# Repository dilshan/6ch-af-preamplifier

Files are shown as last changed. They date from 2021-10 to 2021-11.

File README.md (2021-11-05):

# 5.1 channel audio preamplifier

This project introduces a digitally controlled 5.1 channel audio preamplifier system. This amplifier is specifically designed to increase the gain of the multi-channel PC sound cards.

This preamplifier consists of six *[TL074](https://octopart.com/tl074idt-stmicroelectronics-410591)*/*[TL072](https://octopart.com/tl072idt-stmicroelectronics-410448)* preamplifier stages and *[PT2258](http://www.princeton.com.tw/Portals/0/Product/PT2258.pdf)* electronic volume control. The input stage of this preamplifier consists of six *TL074*/*TL072* buffer stages. The *[PIC16F886](https://www.microchip.com/en-us/product/PIC16F886)* microcontroller manages the *PT2258* electronic volume control IC. All the volume levels and menu options are displayed on [*HD44780*, 16×2 character LCD screen](https://s.click.aliexpress.com/e/_9iRz4T).

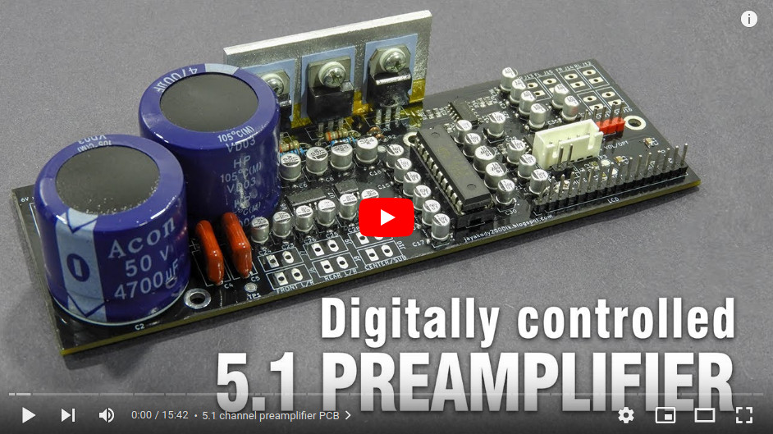
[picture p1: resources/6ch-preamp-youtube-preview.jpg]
5.1 Preamplifier Video (https://youtu.be/Fg2yn0mBOQU)


The provided PCB design contains a preamplifier, buffer stages, digital volume control circuit, driver circuit, and power supply unit.

The project was sponsored by *[PCBWay](https://www.pcbway.com/setinvite.aspx?inviteid=341430)*. The accurately configured PCB of this preamplifier can directly [order from *PCBWay*](https://www.pcbway.com/project/shareproject/5_1_channel_audio_preamplifier.html) through their website. The dimension of the PCB is 151.45 × 50.76mm.

This preamplifier is a [certified](https://certification.oshwa.org/lk000010.html) open hardware project. All source codes, *KiCAD* design files, and compiled binaries are available at this repository.

The complete [documentation](https://github.com/dilshan/6ch-af-preamplifier/wiki) of this project is available in the [wiki](https://github.com/dilshan/6ch-af-preamplifier/wiki) section of this repository. The PCB *Gerber files* and compiled binaries are also available in the [release](https://github.com/dilshan/6ch-af-preamplifier/releases) section of this repository.

All the content of this project are distributed under the terms of the following license:

- Hardware License: [CERN-OHL-W 2.0](https://ohwr.org/cern_ohl_w_v2.txt)
- Software License: [MIT](https://github.com/dilshan/6ch-af-preamplifier/blob/main/LICENSE)
- [Documentation](https://github.com/dilshan/6ch-af-preamplifier/wiki) License: [CC BY 4.0](https://creativecommons.org/licenses/by/4.0/)

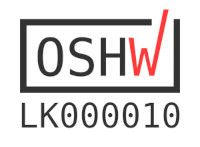
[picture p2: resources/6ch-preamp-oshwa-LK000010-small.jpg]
LK000010 (https://certification.oshwa.org/lk000010.html)


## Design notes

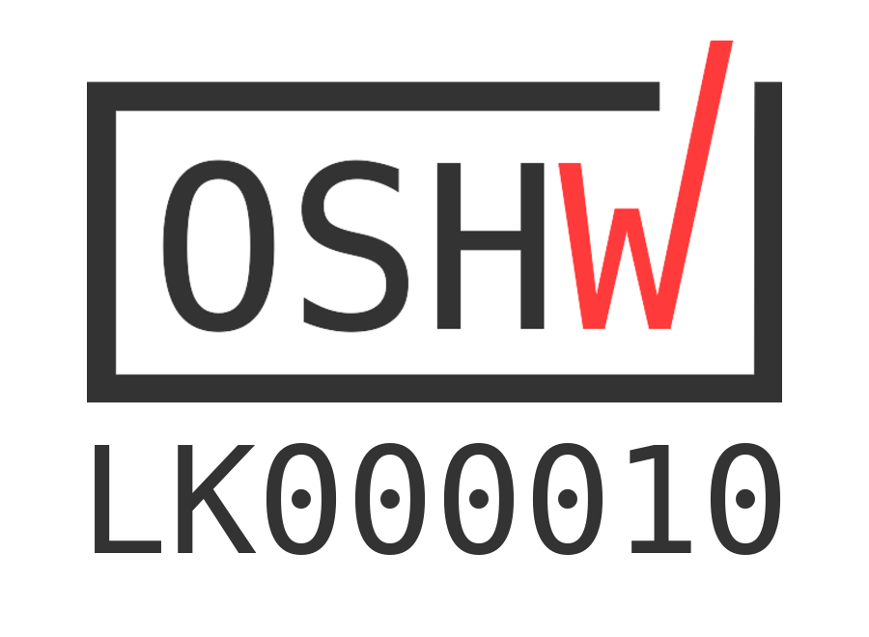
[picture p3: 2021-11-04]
resources/6ch-preamp-oshwa-LK000010.png

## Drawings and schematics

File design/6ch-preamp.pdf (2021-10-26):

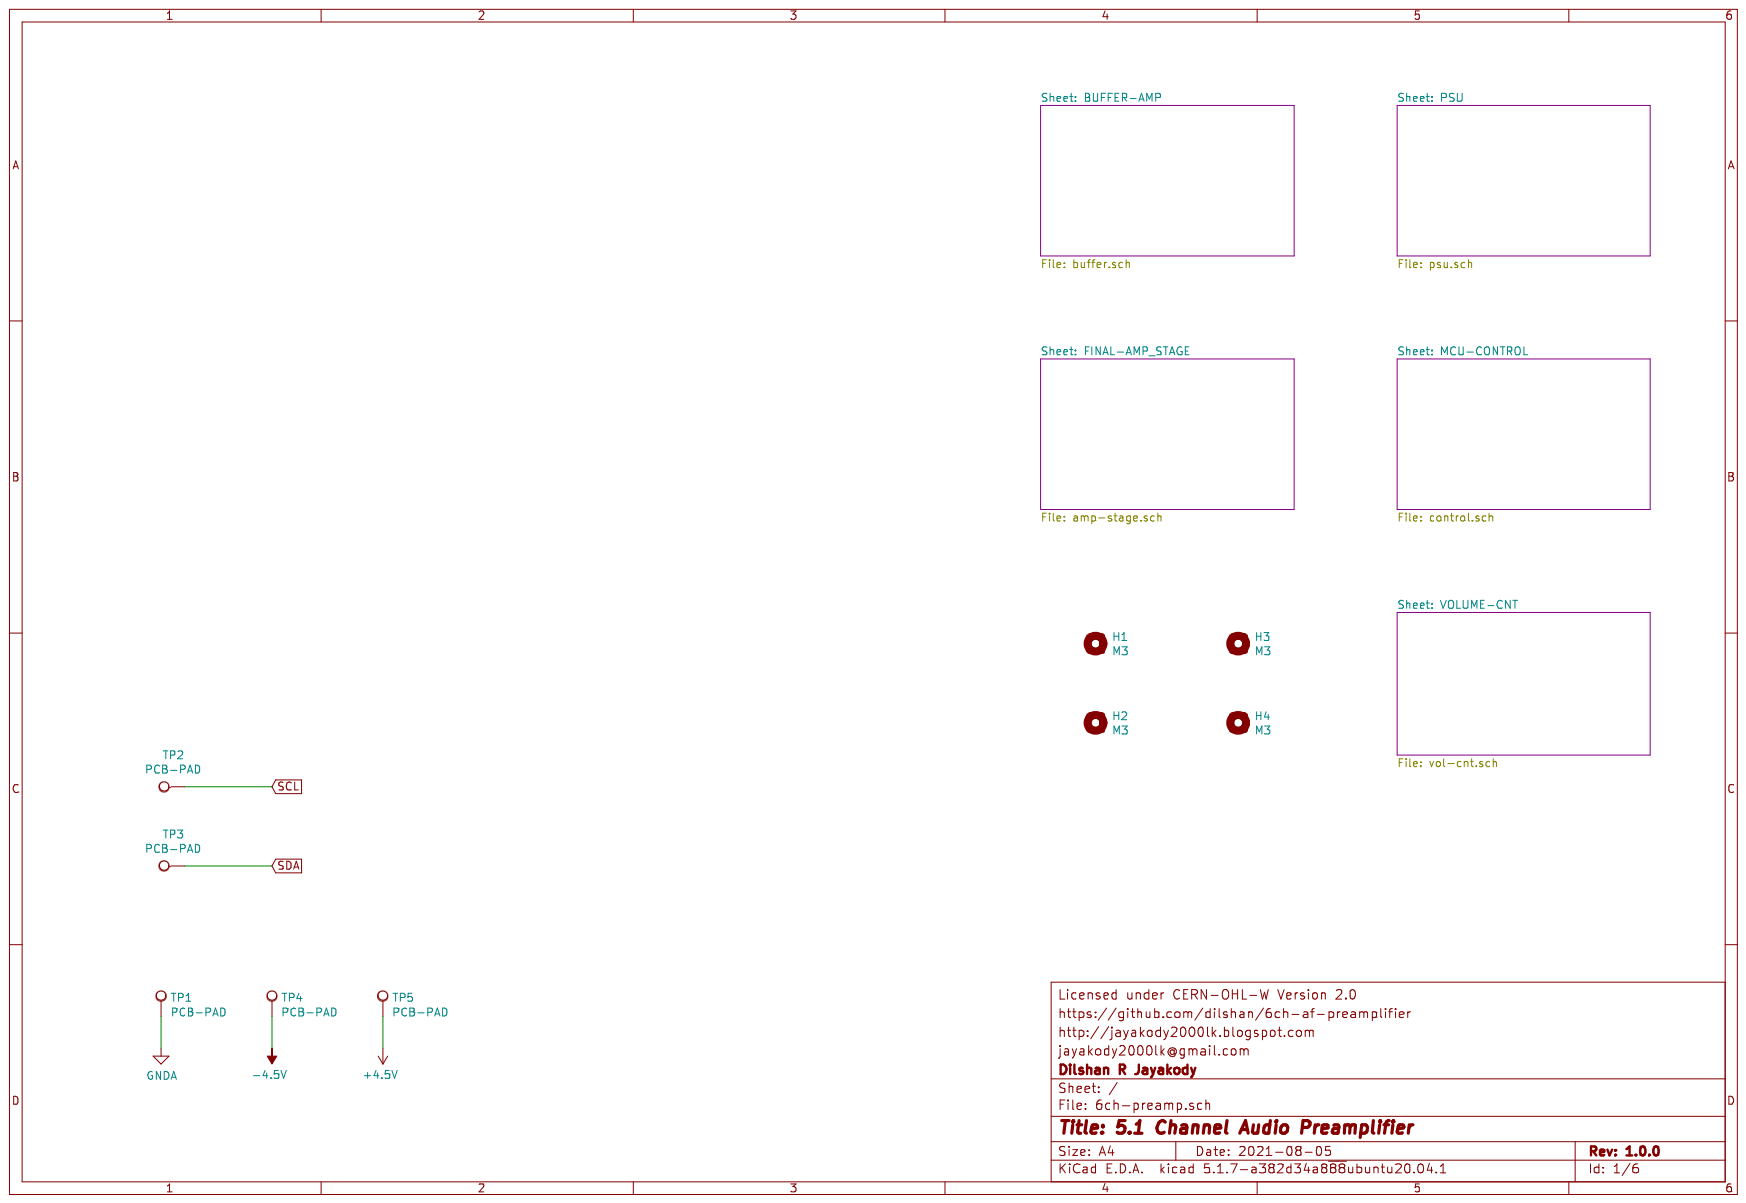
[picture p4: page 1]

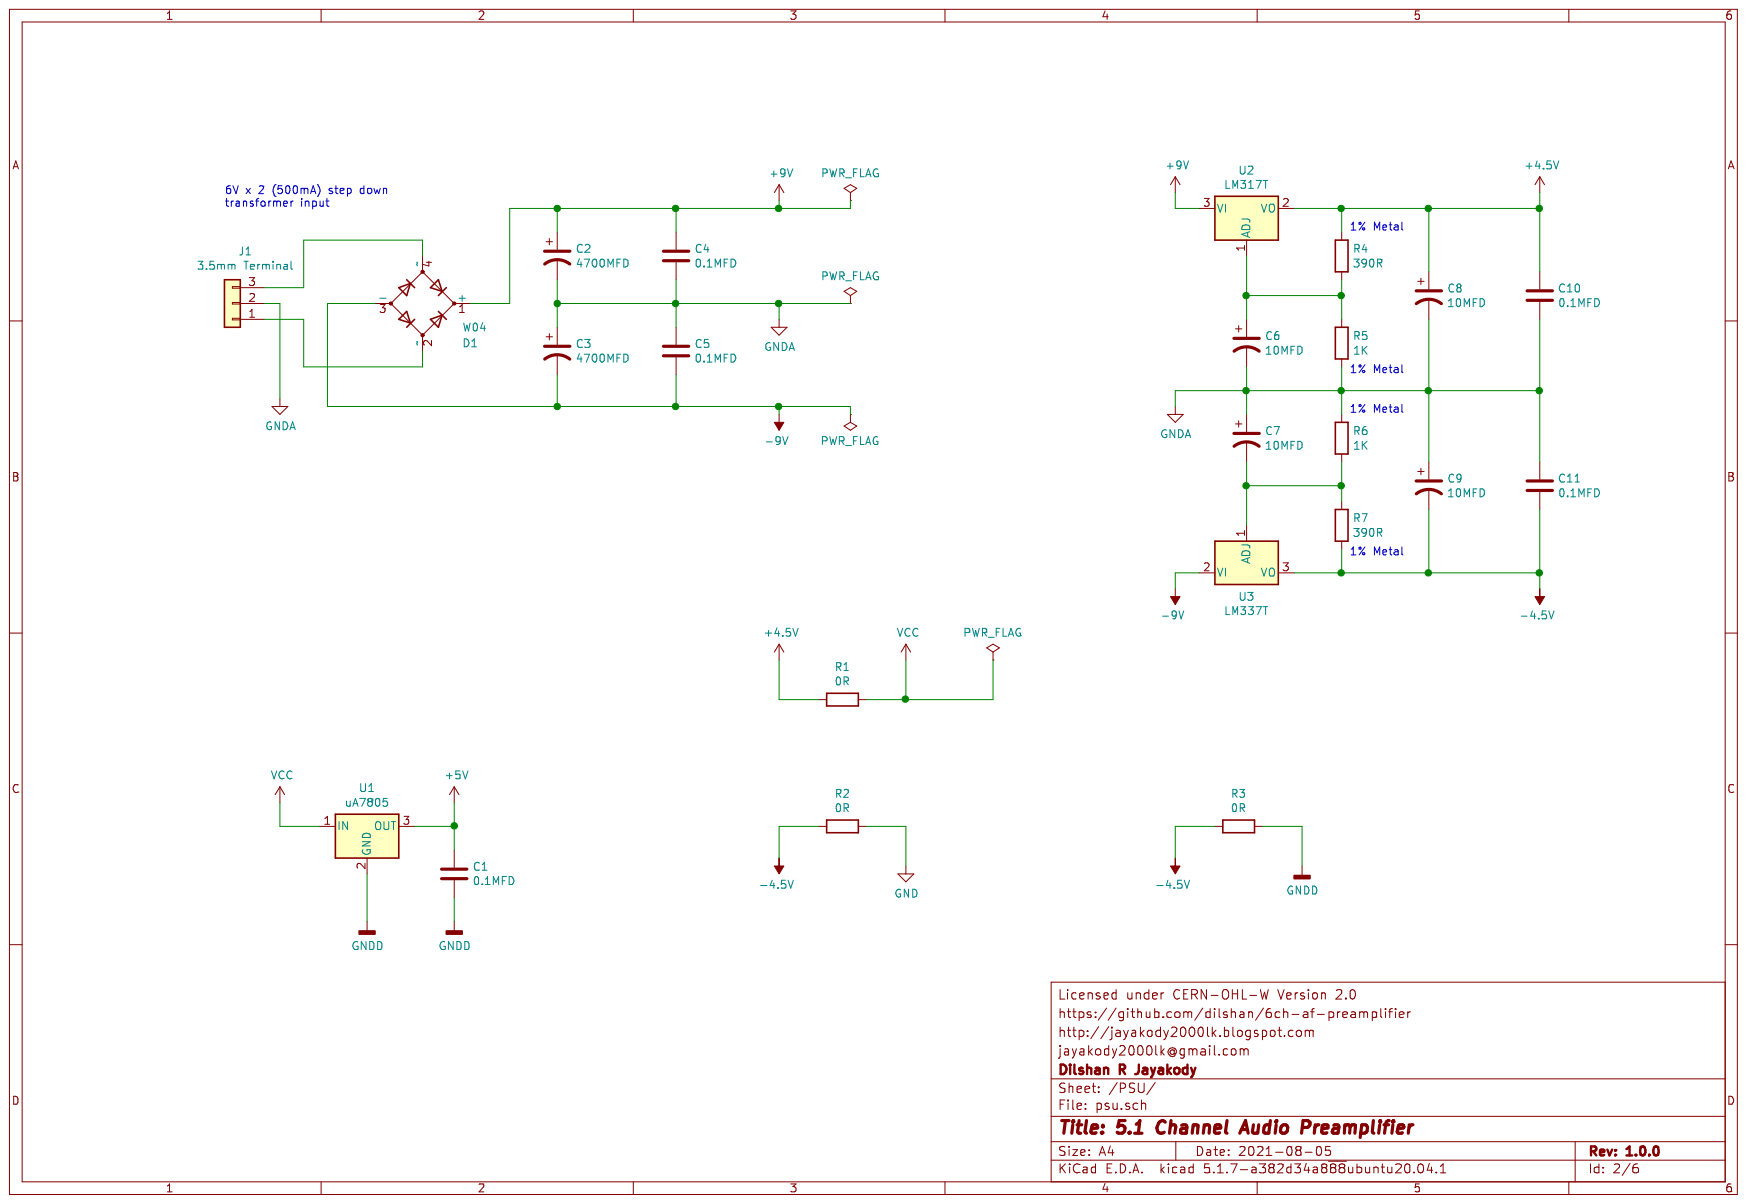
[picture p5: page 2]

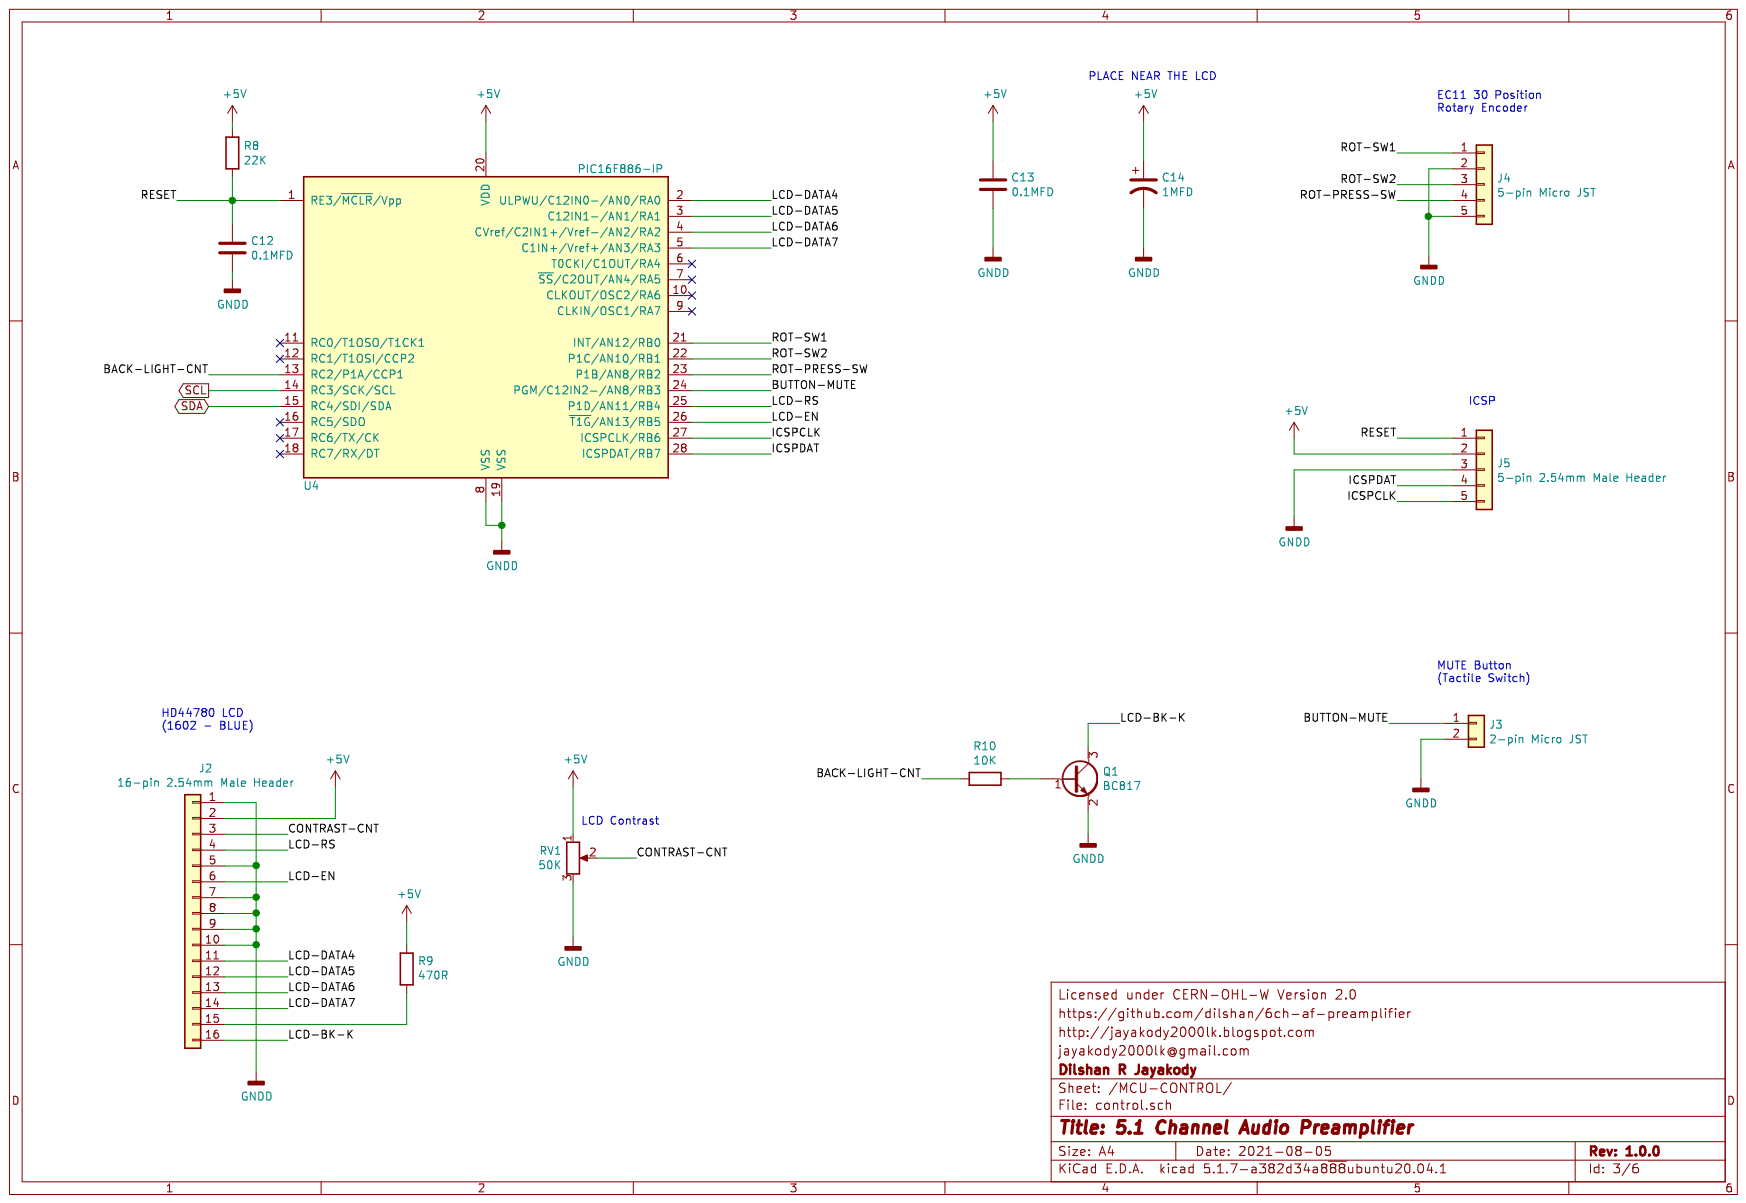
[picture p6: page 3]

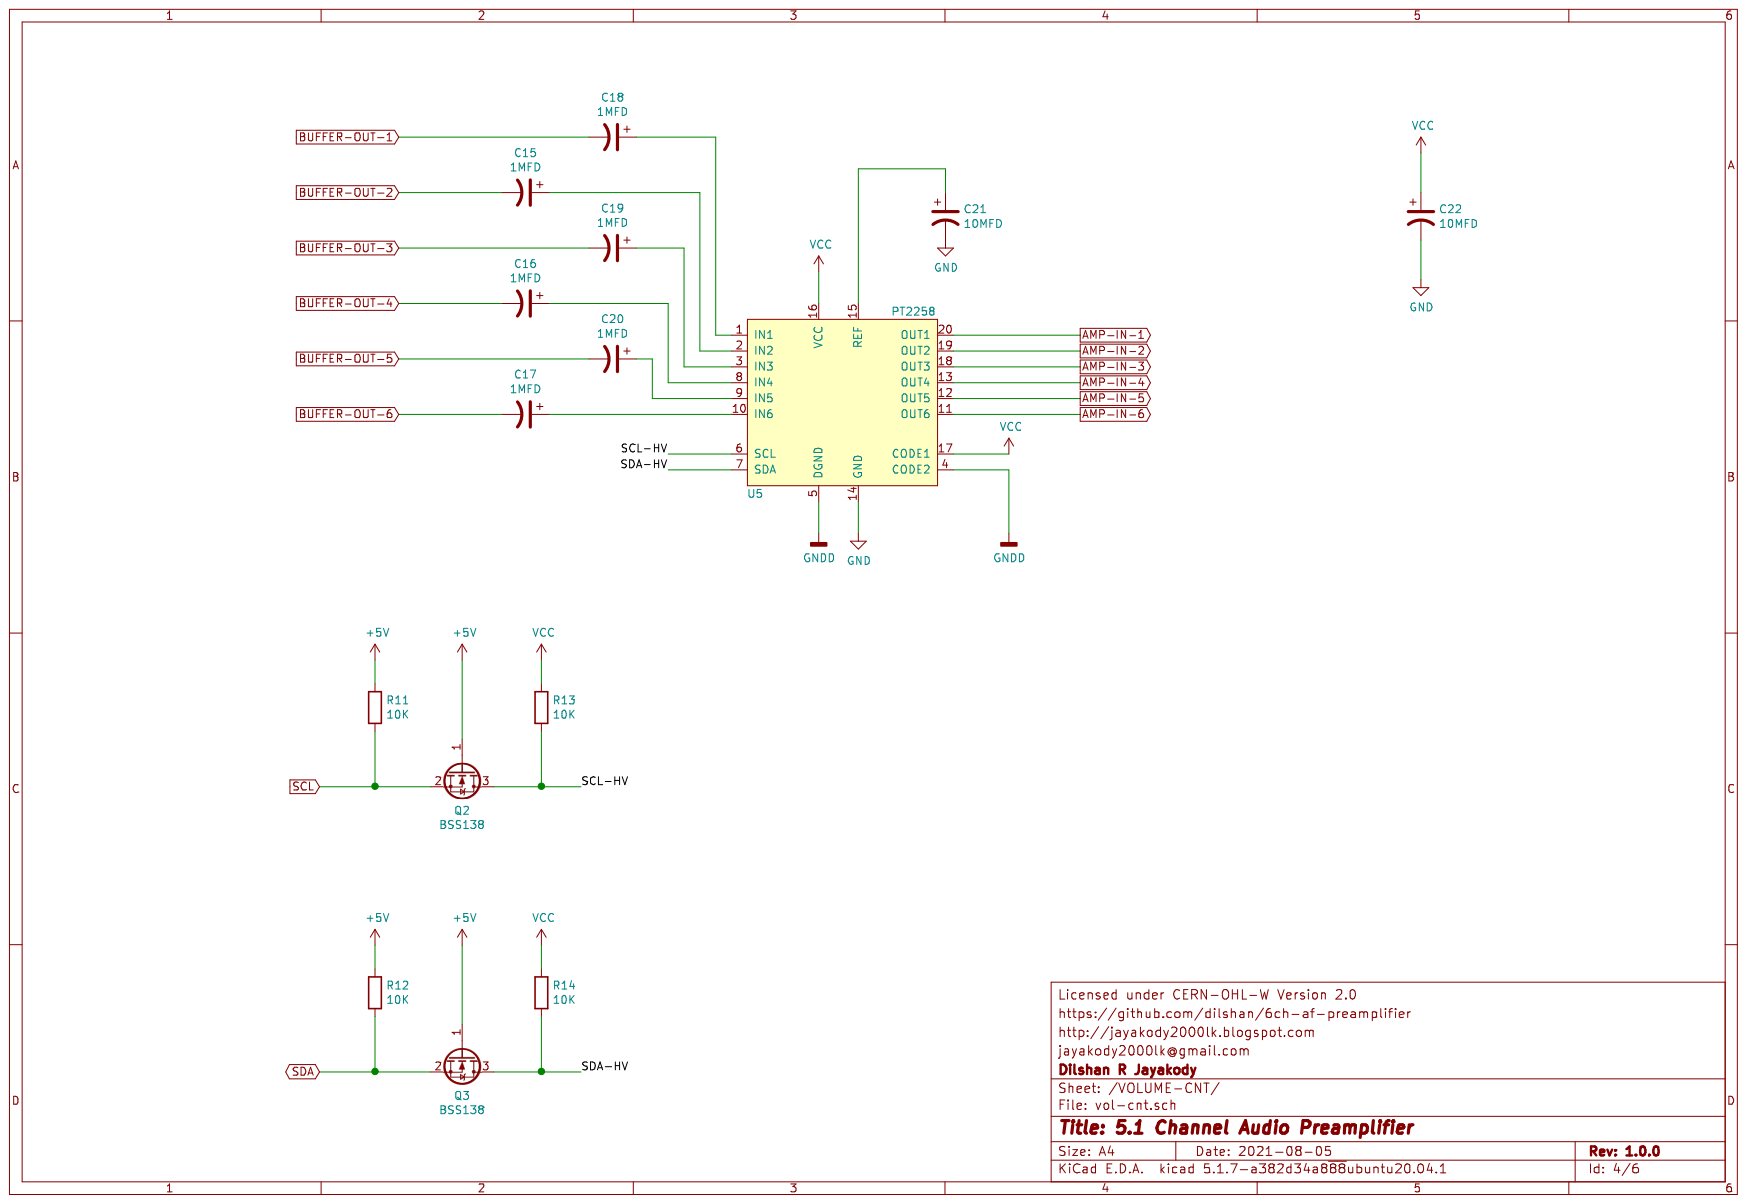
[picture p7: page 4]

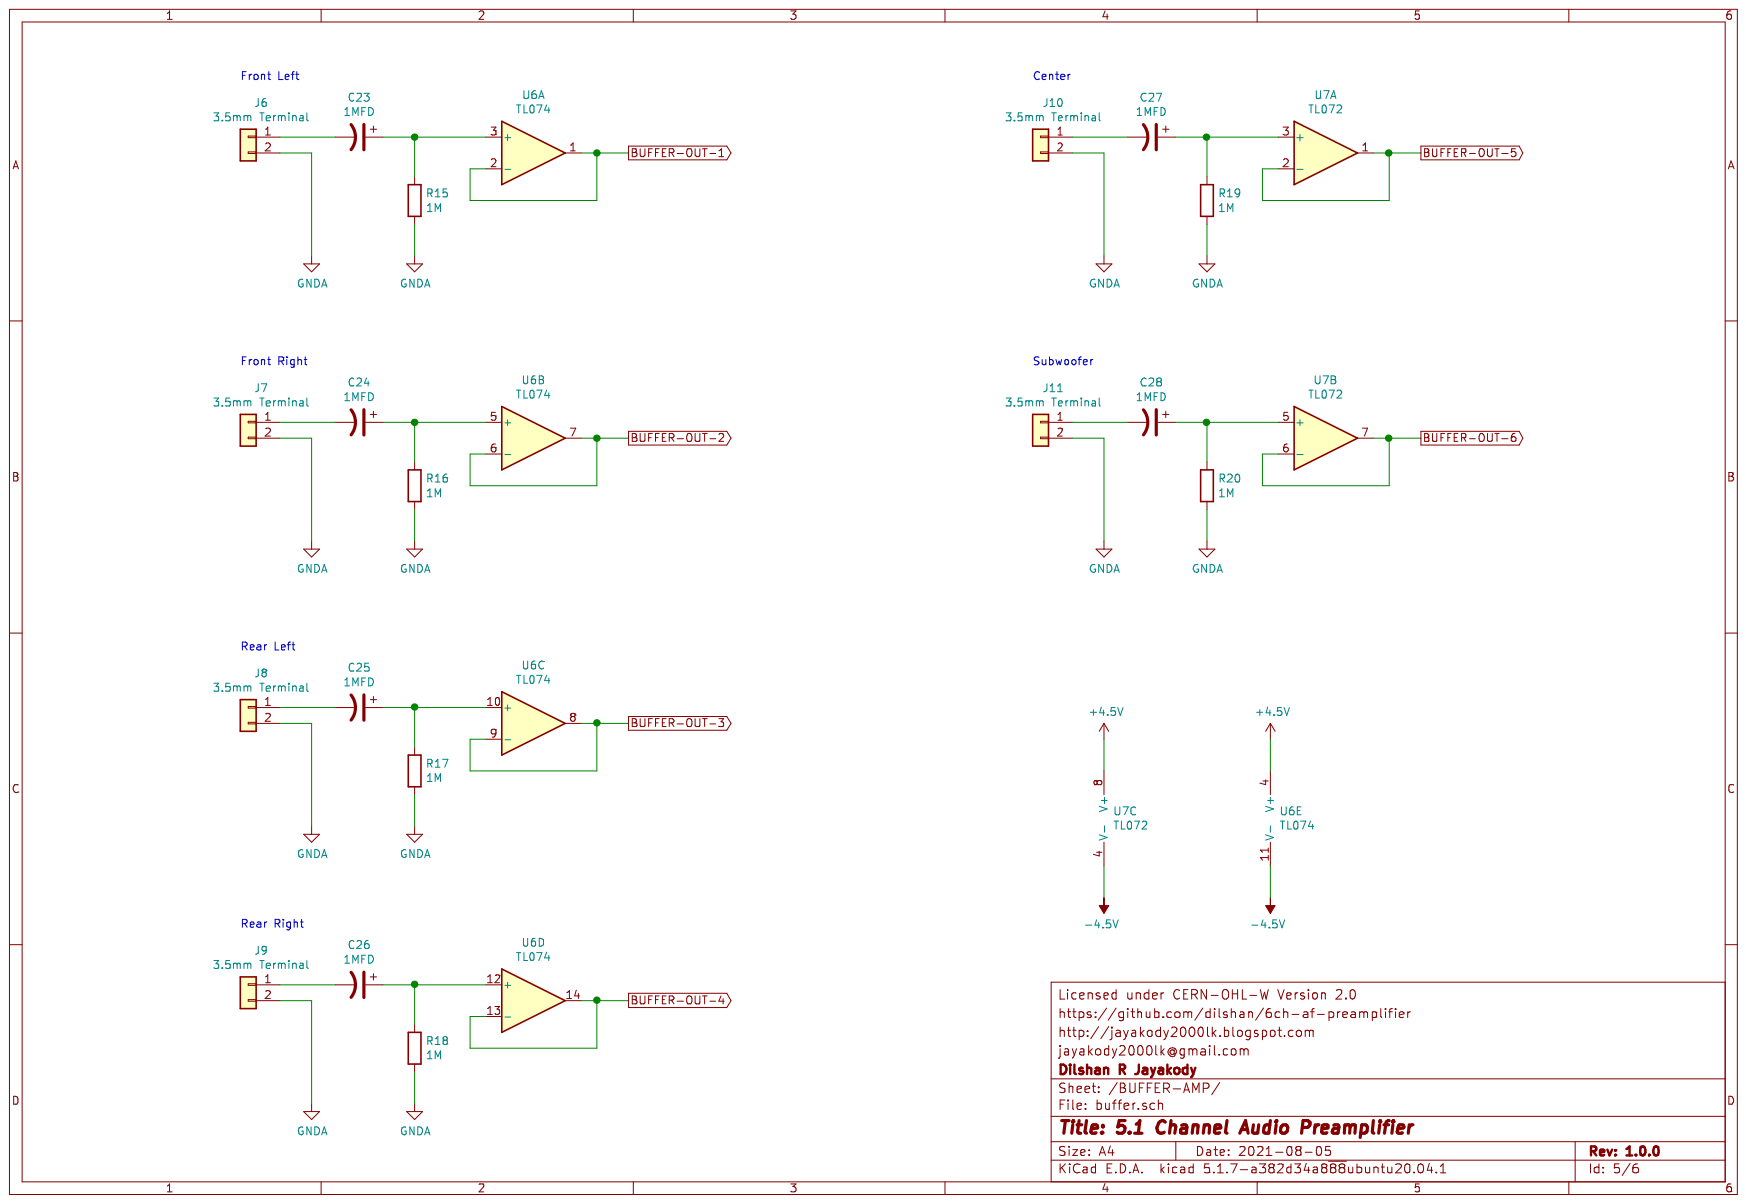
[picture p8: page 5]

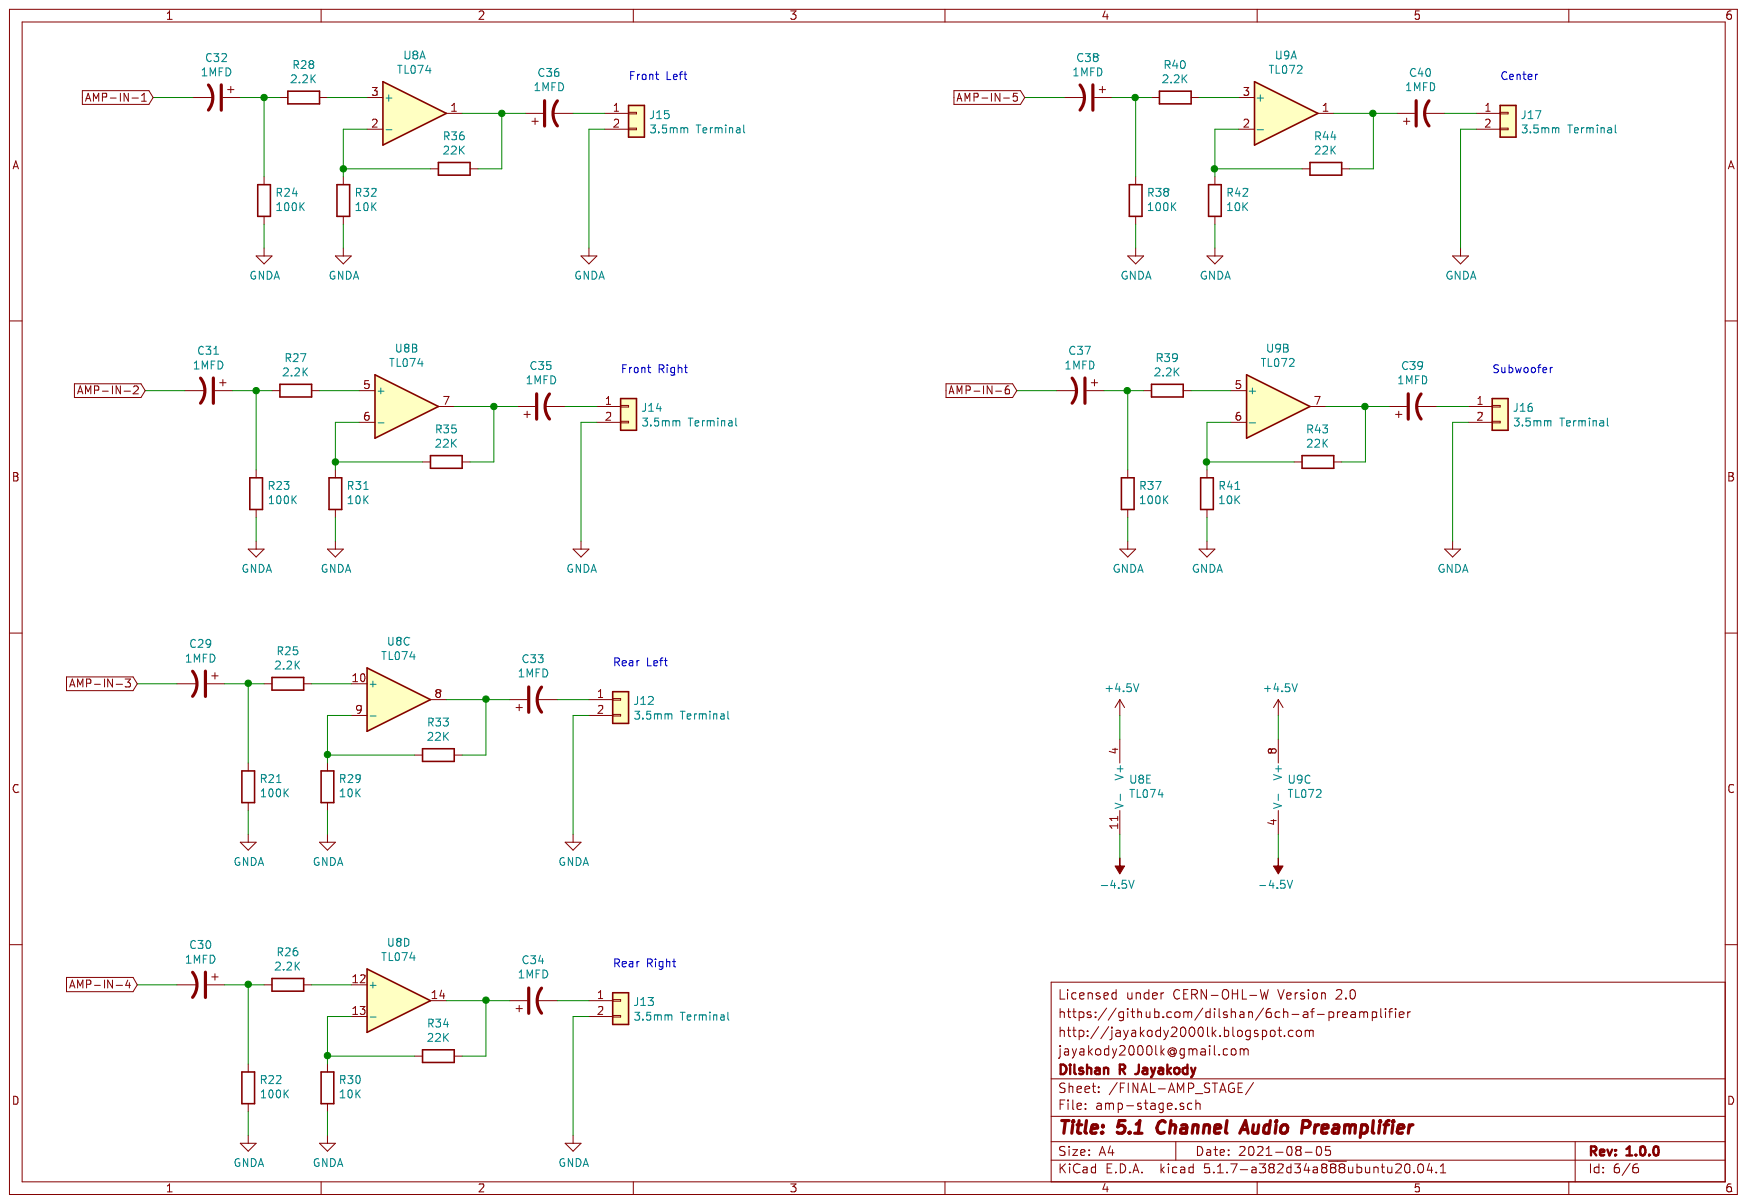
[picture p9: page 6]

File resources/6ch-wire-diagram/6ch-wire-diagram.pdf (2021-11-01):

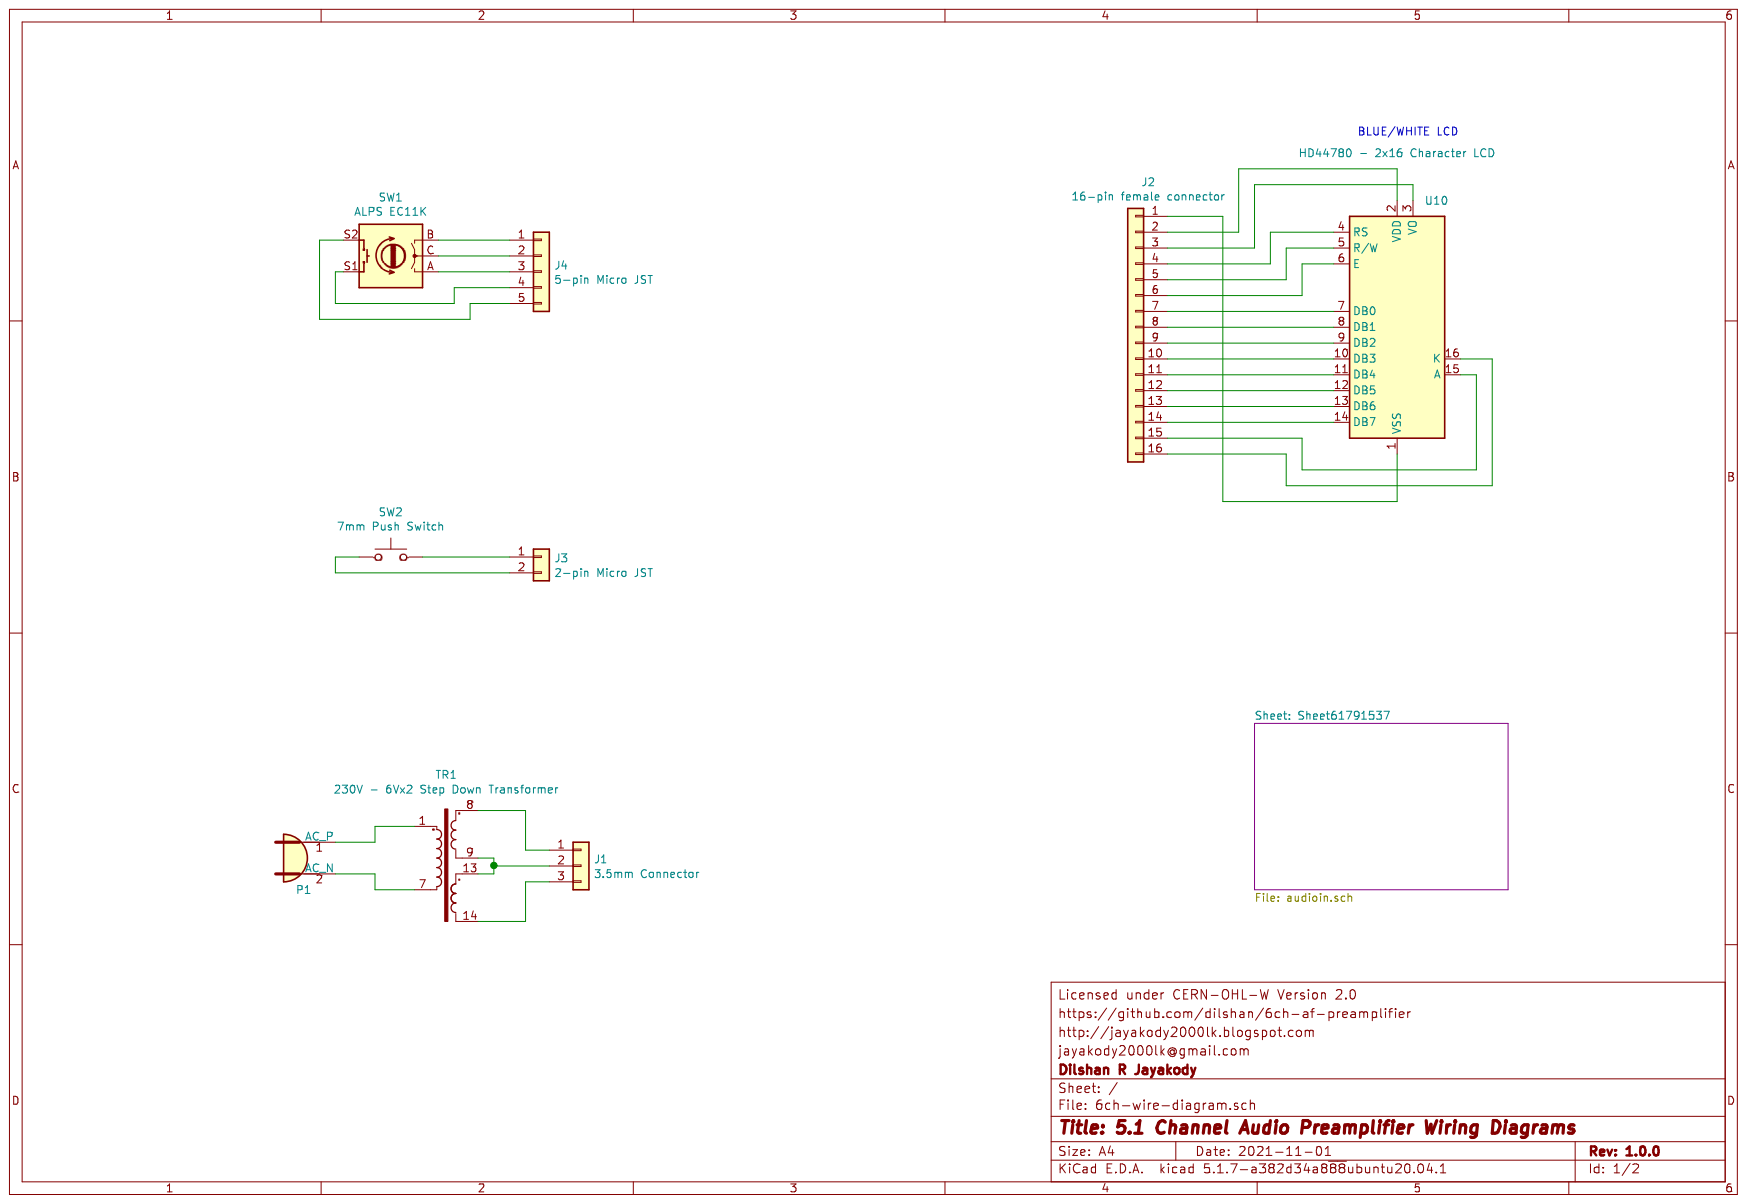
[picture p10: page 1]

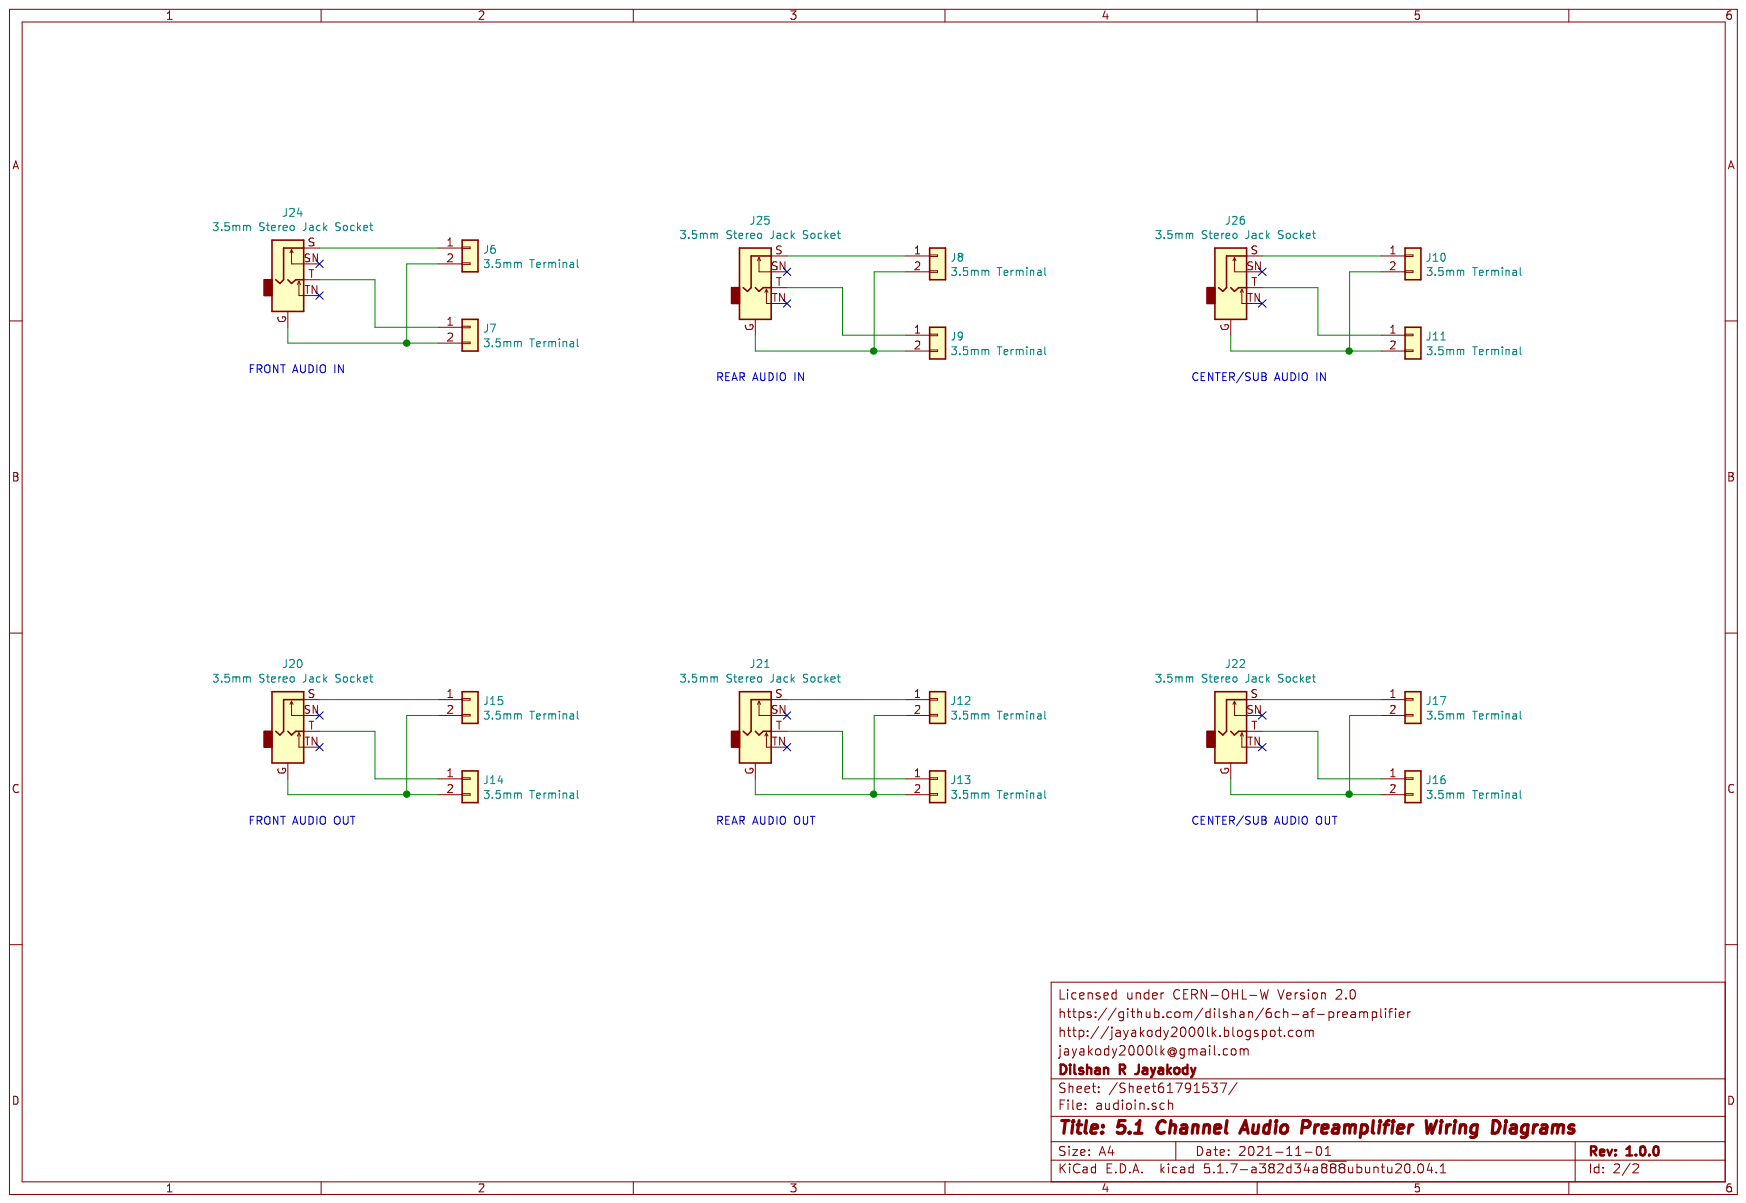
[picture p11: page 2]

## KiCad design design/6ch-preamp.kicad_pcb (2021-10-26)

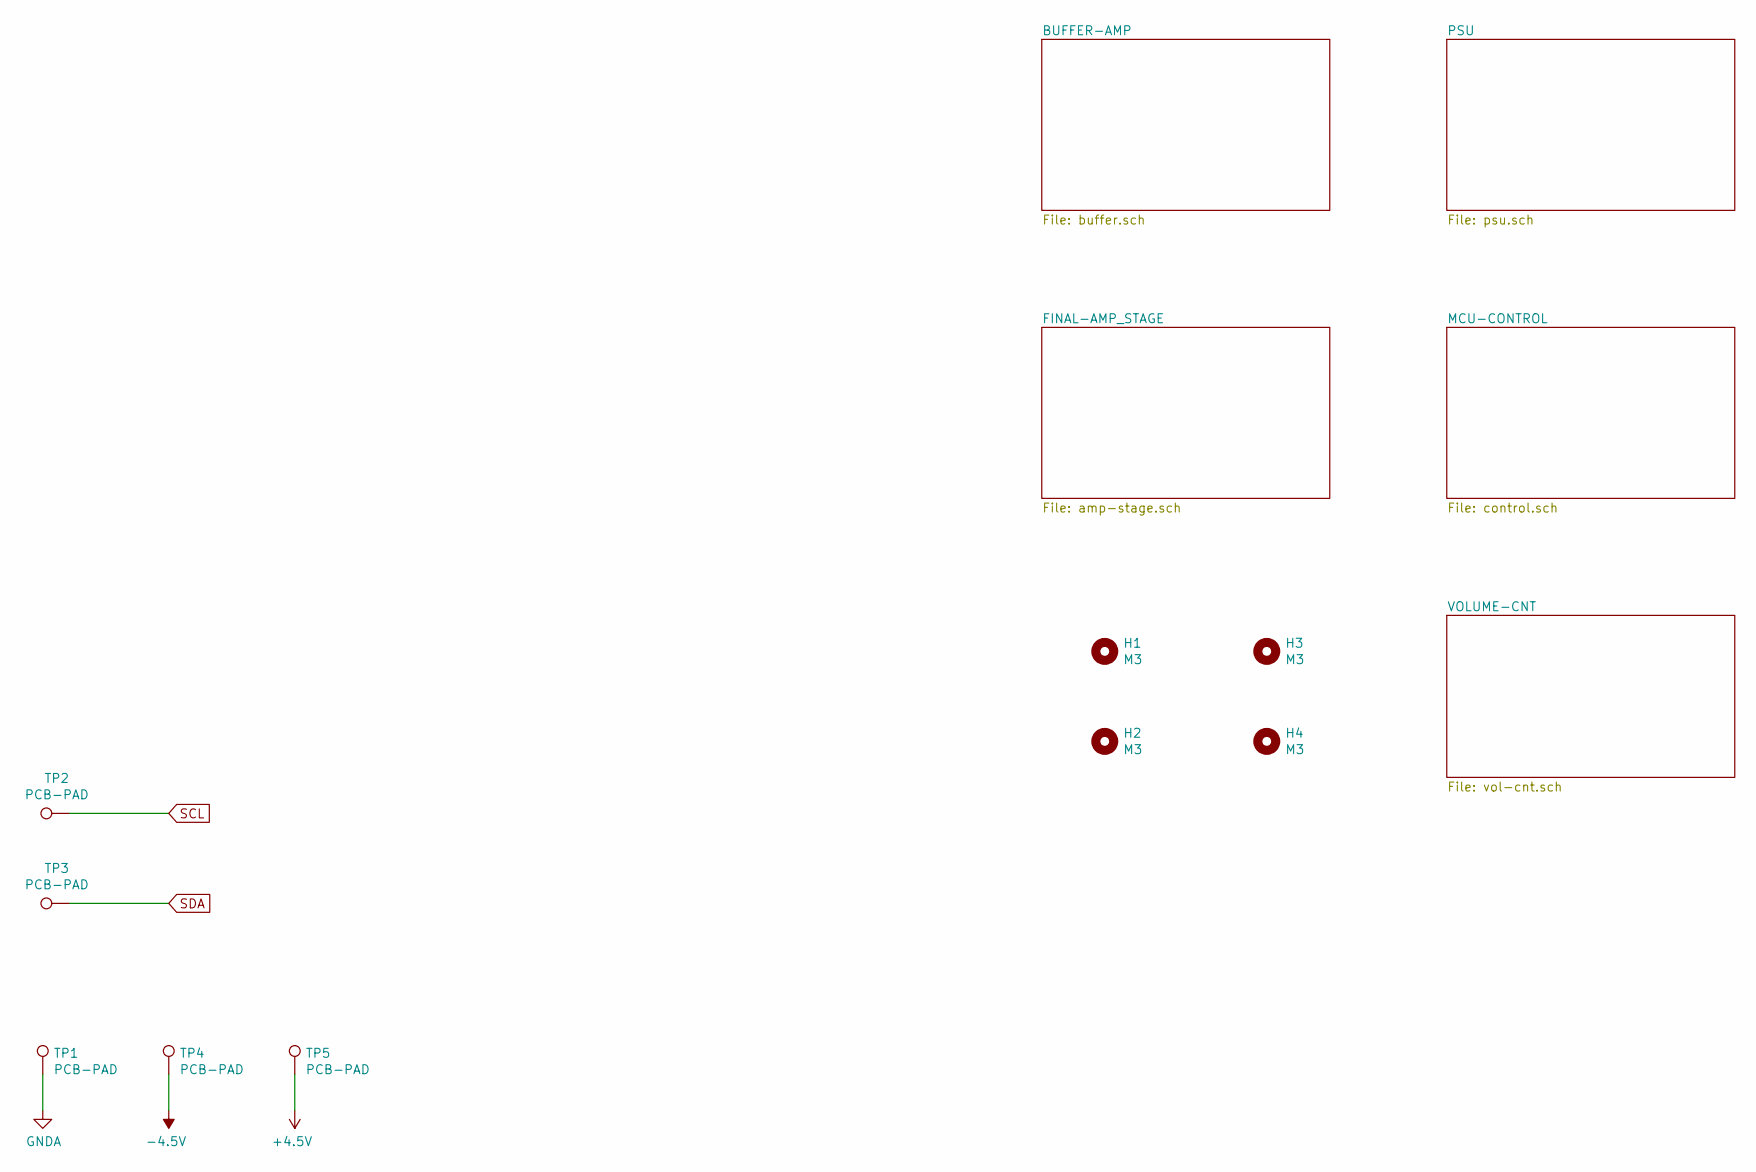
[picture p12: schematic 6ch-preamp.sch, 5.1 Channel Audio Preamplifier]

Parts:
H1, H2, H3, H4: M3; MountingHole_3.2mm_M3_DIN965_Pad
TP1, TP2, TP3, TP4, TP5: PCB-PAD; TestPoint_Pad_D2.0mm

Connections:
+1V35: TP5.1; also elsewhere on the board
-5V: TP4.1; also elsewhere on the board
GNDA: TP1.1; also elsewhere on the board
SCL: TP2.1; also elsewhere on the board
SDA: TP3.1; also elsewhere on the board

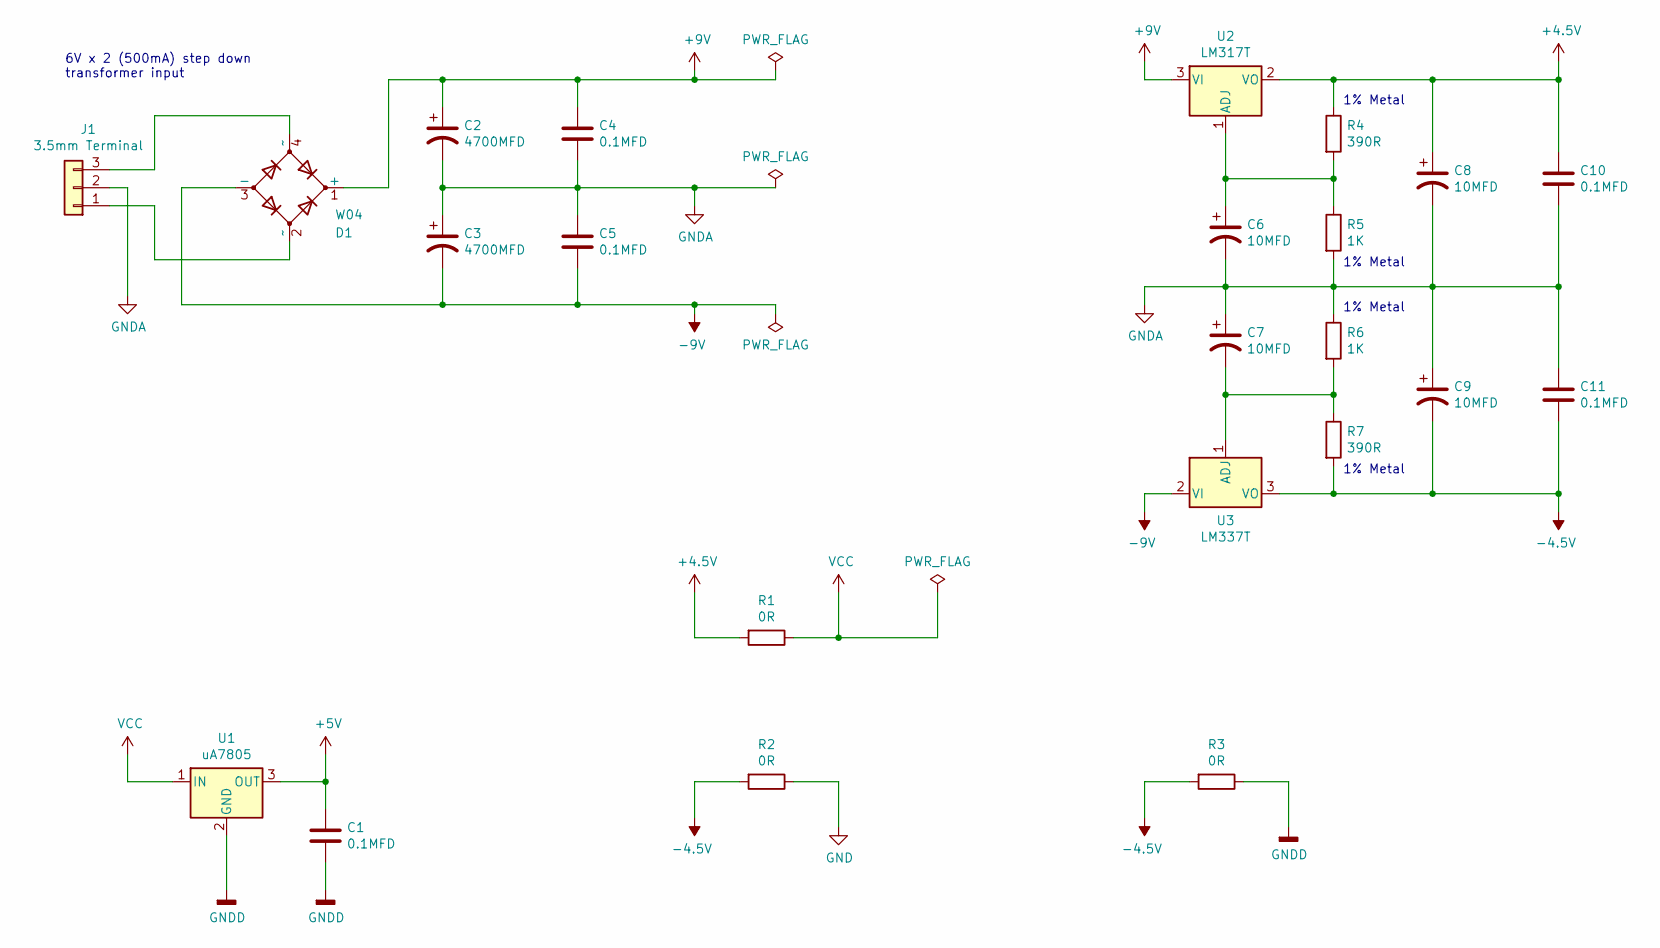
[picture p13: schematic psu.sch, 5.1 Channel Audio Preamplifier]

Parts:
C1, C10, C11: 0.1MFD; C_0805_2012Metric_Pad1.18x1.45mm_HandSolder
C2, C3: 4700MFD; CP_Radial_D30.0mm_P10.00mm_SnapIn
C4, C5: 0.1MFD; C_Disc_D10.5mm_W5.0mm_P10.00mm
C6, C7, C8, C9: 10MFD; CP_Elec_5x5.3
D1: W04; Diode_Bridge_Round_D9.0mm
J1: 3.5mm Terminal; PhoenixContact_MCV_1,5_3-G-3.5_1x03_P3.50mm_Vertical
R1, R2, R3: 0R; R_Axial_DIN0204_L3.6mm_D1.6mm_P2.54mm_Vertical
R4, R7: 390R; R_Axial_DIN0207_L6.3mm_D2.5mm_P10.16mm_Horizontal
R5, R6: 1K; R_Axial_DIN0207_L6.3mm_D2.5mm_P10.16mm_Horizontal
U1: uA7805; TO-220-3_Vertical
U2: LM317T; TO-220-3_Vertical
U3: LM337T; TO-220-3_Vertical

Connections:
+1V35: C8.1, C10.1, R1.2, R4.1, U2.2 (VO); also elsewhere on the board
+5V: C1.1, U1.3 (OUT); also elsewhere on the board
+9V: C2.1, C4.1, D1.1 (+), U2.3 (VI)
-5V: C9.2, C11.2, R2.2, R3.2, R7.2, U3.3 (VO); also elsewhere on the board
-9V: C3.2, C5.2, D1.3 (-), U3.2 (VI)
GND: R2.1; also elsewhere on the board
GNDA: C2.2, C3.1, C4.2, C5.1, C6.2, C7.1, C8.2, C9.1, C10.2, C11.1, J1.2, R5.2, R6.1; also elsewhere on the board
GNDD: C1.2, R3.1, U1.2 (GND); also elsewhere on the board
unnamed: C6.1, R4.2, R5.1, U2.1 (ADJ)
unnamed: C7.2, R6.2, R7.1, U3.1 (ADJ)
unnamed: D1.2 (~~), J1.1
unnamed: D1.4 (~~), J1.3
VCC: R1.1, U1.1 (IN); also elsewhere on the board

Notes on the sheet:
6V x 2 (500mA) step down transformer input
1% Metal

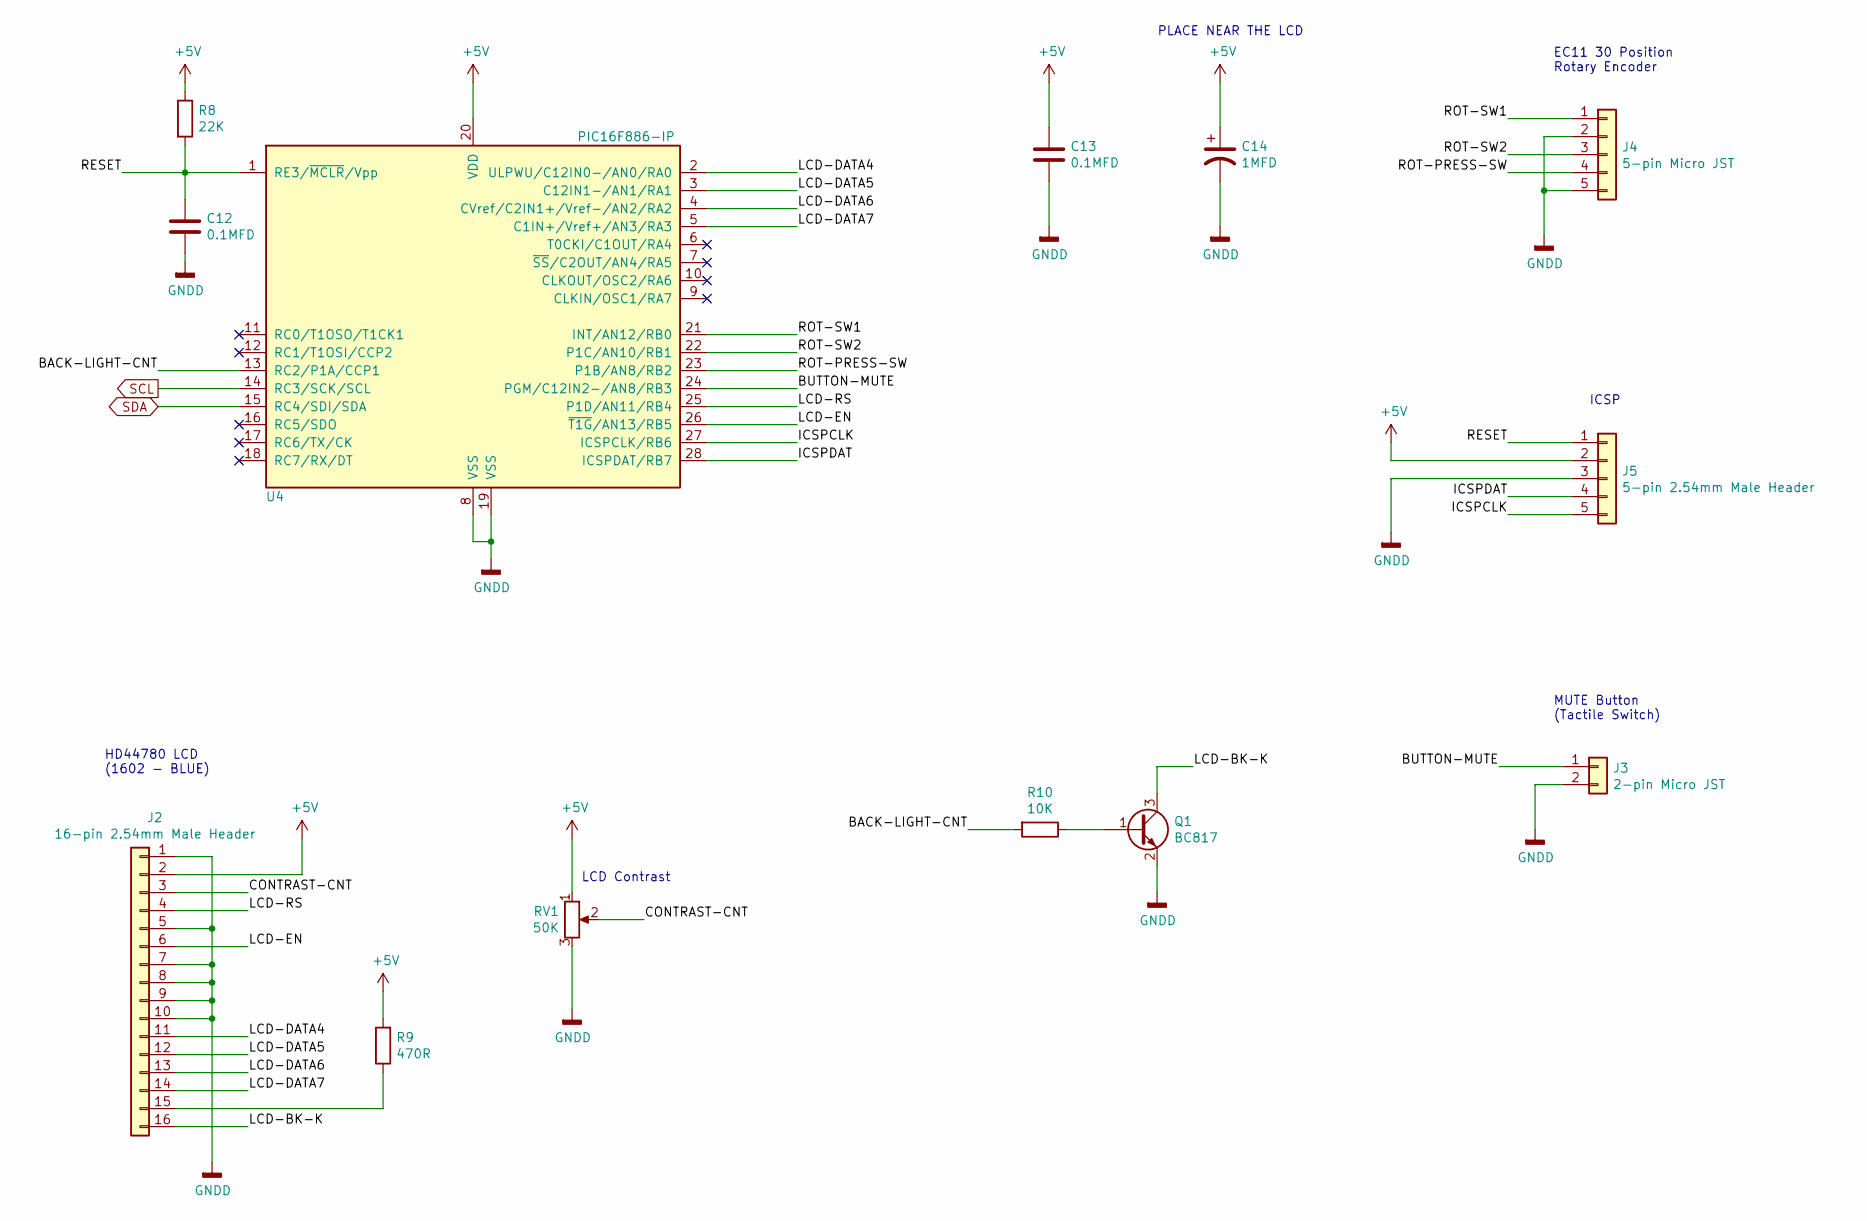
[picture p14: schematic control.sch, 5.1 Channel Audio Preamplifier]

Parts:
C12, C13: 0.1MFD; C_0805_2012Metric_Pad1.18x1.45mm_HandSolder
C14: 1MFD; CP_Elec_4x5.3
J2: 16-pin 2.54mm Male Header; PinHeader_1x16_P2.54mm_Vertical
J3: 2-pin Micro JST; JST_EH_B2B-EH-A_1x02_P2.50mm_Vertical
J4: 5-pin Micro JST; JST_EH_B5B-EH-A_1x05_P2.50mm_Vertical
J5: 5-pin 2.54mm Male Header; PinHeader_1x05_P2.54mm_Vertical
Q1: BC817; SOT-23
R8: 22K; R_0805_2012Metric_Pad1.20x1.40mm_HandSolder
R9: 470R; R_0805_2012Metric_Pad1.20x1.40mm_HandSolder
R10: 10K; R_0805_2012Metric_Pad1.20x1.40mm_HandSolder
RV1: 50K; Potentiometer_Bourns_TC33X_Vertical
U4: PIC16F886-IP; SSOP-28_5.3x10.2mm_P0.65mm

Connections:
+5V: C13.1, C14.1, J2.2, J5.2, R8.1, R9.2, RV1.1, U4.20 (VDD); also elsewhere on the board
/MCU-CONTROL/BACK-LIGHT-CNT: R10.2, U4.13 (RC2/P1A/CCP1)
/MCU-CONTROL/BUTTON-MUTE: J3.1, U4.24 (PGM/C12IN2-/AN8/RB3)
/MCU-CONTROL/CONTRAST-CNT: J2.3, RV1.2
/MCU-CONTROL/ICSPCLK: J5.5, U4.27 (ICSPCLK/RB6)
/MCU-CONTROL/ICSPDAT: J5.4, U4.28 (ICSPDAT/RB7)
/MCU-CONTROL/LCD-BK-K: J2.16, Q1.3 (C)
/MCU-CONTROL/LCD-DATA4: J2.11, U4.2 (ULPWU/C12IN0-/AN0/RA0)
/MCU-CONTROL/LCD-DATA5: J2.12, U4.3 (C12IN1-/AN1/RA1)
/MCU-CONTROL/LCD-DATA6: J2.13, U4.4 (CVref/C2IN1+/Vref-/AN2/RA2)
/MCU-CONTROL/LCD-DATA7: J2.14, U4.5 (C1IN+/Vref+/AN3/RA3)
/MCU-CONTROL/LCD-EN: J2.6, U4.26 (~T1G~/AN13/RB5)
/MCU-CONTROL/LCD-RS: J2.4, U4.25 (P1D/AN11/RB4)
/MCU-CONTROL/RESET: C12.1, J5.1, R8.2, U4.1 (RE3/~MCLR~/Vpp)
/MCU-CONTROL/ROT-PRESS-SW: J4.4, U4.23 (P1B/AN8/RB2)
/MCU-CONTROL/ROT-SW1: J4.1, U4.21 (INT/AN12/RB0)
/MCU-CONTROL/ROT-SW2: J4.3, U4.22 (P1C/AN10/RB1)
GNDD: C12.2, C13.2, C14.2, J2.1, J2.5, J2.7, J2.8, J2.9, J2.10, J3.2, J4.2, J4.5, J5.3, Q1.2 (E), RV1.3, U4.8 (VSS), U4.19 (VSS); also elsewhere on the board
unnamed: J2.15, R9.1
unnamed: Q1.1 (B), R10.1
SCL: U4.14 (RC3/SCK/SCL); also elsewhere on the board
SDA: U4.15 (RC4/SDI/SDA); also elsewhere on the board

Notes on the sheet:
EC11 30 Position Rotary Encoder
ICSP
MUTE Button (Tactile Switch)
HD44780 LCD (1602 - BLUE)
LCD Contrast
PLACE NEAR THE LCD

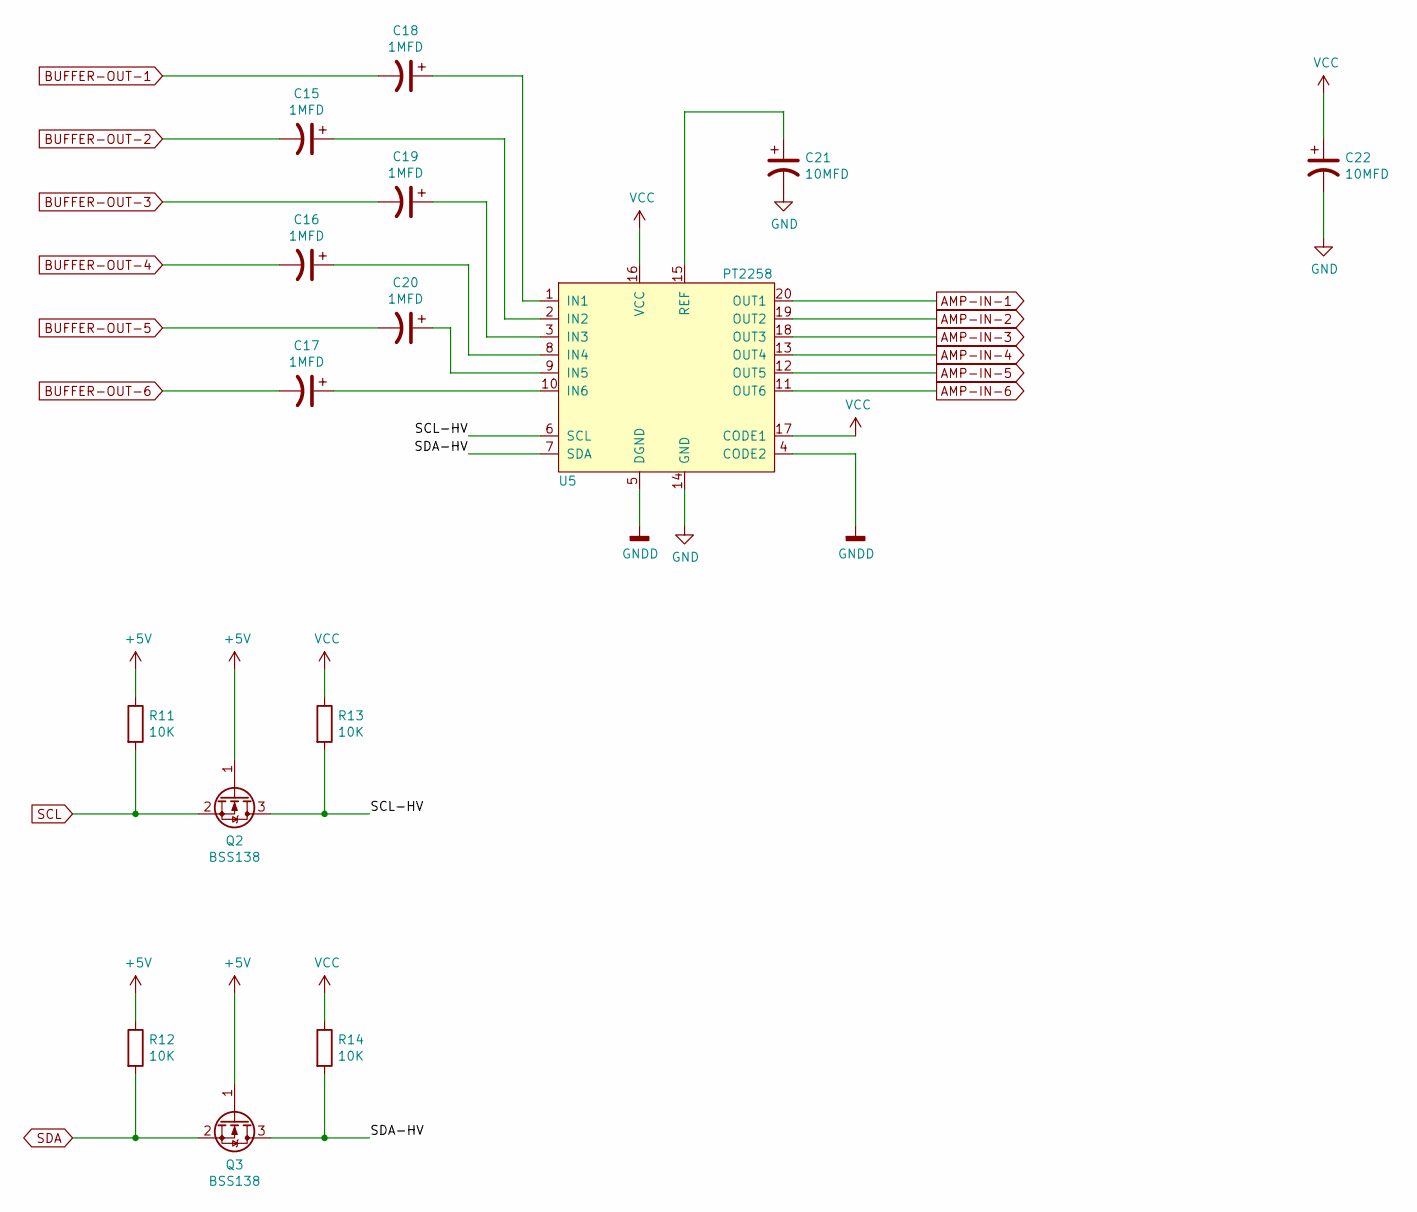
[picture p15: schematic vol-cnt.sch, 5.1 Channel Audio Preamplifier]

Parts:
C15, C16, C17, C18, C19, C20: 1MFD; CP_Elec_4x5.3
C21, C22: 10MFD; CP_Elec_5x5.3
Q2, Q3: BSS138; SOT-23
R11, R12, R13, R14: 10K; R_0805_2012Metric_Pad1.20x1.40mm_HandSolder
U5: PT2258; DIP-20_W7.62mm_LongPads

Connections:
+5V: Q2.1 (G), Q3.1 (G), R11.1, R12.1; also elsewhere on the board
/VOLUME-CNT/SCL-HV: Q2.3 (D), R13.2, U5.6 (SCL)
/VOLUME-CNT/SDA-HV: Q3.3 (D), R14.2, U5.7 (SDA)
AMP-IN-1: U5.20 (OUT1); also elsewhere on the board
AMP-IN-2: U5.19 (OUT2); also elsewhere on the board
AMP-IN-3: U5.18 (OUT3); also elsewhere on the board
AMP-IN-4: U5.13 (OUT4); also elsewhere on the board
AMP-IN-5: U5.12 (OUT5); also elsewhere on the board
AMP-IN-6: U5.11 (OUT6); also elsewhere on the board
BUFFER-OUT-1: C18.2; also elsewhere on the board
BUFFER-OUT-2: C15.2; also elsewhere on the board
BUFFER-OUT-3: C19.2; also elsewhere on the board
BUFFER-OUT-4: C16.2; also elsewhere on the board
BUFFER-OUT-5: C20.2; also elsewhere on the board
BUFFER-OUT-6: C17.2; also elsewhere on the board
GND: C21.2, C22.2, U5.14 (GND); also elsewhere on the board
GNDD: U5.4 (CODE2), U5.5 (DGND); also elsewhere on the board
unnamed: C15.1, U5.2 (IN2)
unnamed: C16.1, U5.8 (IN4)
unnamed: C17.1, U5.10 (IN6)
unnamed: C18.1, U5.1 (IN1)
unnamed: C19.1, U5.3 (IN3)
unnamed: C20.1, U5.9 (IN5)
unnamed: C21.1, U5.15 (REF)
SCL: Q2.2 (S), R11.2; also elsewhere on the board
SDA: Q3.2 (S), R12.2; also elsewhere on the board
VCC: C22.1, R13.1, R14.1, U5.16 (VCC), U5.17 (CODE1); also elsewhere on the board

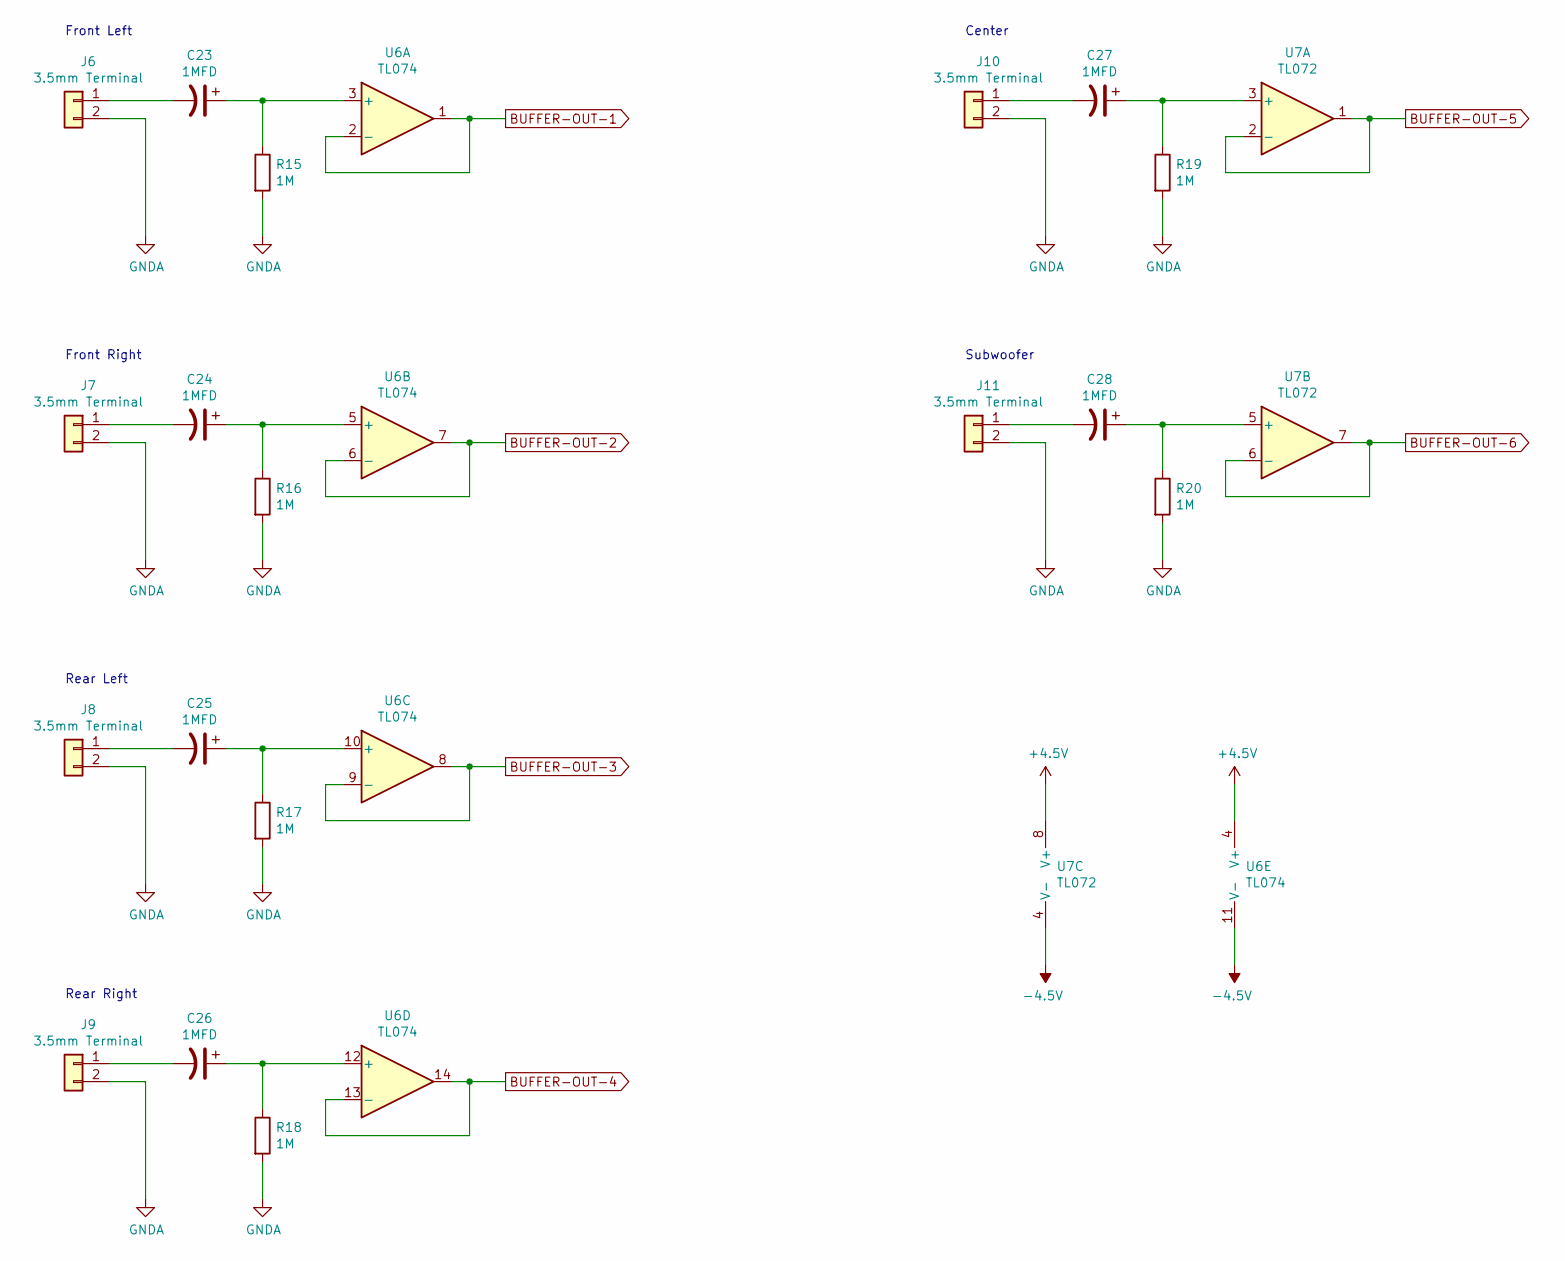
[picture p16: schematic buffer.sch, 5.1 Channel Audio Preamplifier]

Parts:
C23, C24, C25, C26, C27, C28: 1MFD; CP_Elec_4x5.3
J6, J7, J8, J9, J10, J11: 3.5mm Terminal; 3.50mm_PCB_Terminal
R15, R16, R17, R18, R19, R20: 1M; R_0805_2012Metric_Pad1.20x1.40mm_HandSolder
U6: TL074; SO-14_3.9x8.65mm_P1.27mm
U7: TL072; SO-8_3.9x4.9mm_P1.27mm

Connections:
+1V35: U6.4 (V+), U7.8 (V+); also elsewhere on the board
-5V: U6.11 (V-), U7.4 (V-); also elsewhere on the board
BUFFER-OUT-1: U6.1, U6.2 (-); also elsewhere on the board
BUFFER-OUT-2: U6.6 (-), U6.7; also elsewhere on the board
BUFFER-OUT-3: U6.8, U6.9 (-); also elsewhere on the board
BUFFER-OUT-4: U6.13 (-), U6.14; also elsewhere on the board
BUFFER-OUT-5: U7.1, U7.2 (-); also elsewhere on the board
BUFFER-OUT-6: U7.6 (-), U7.7; also elsewhere on the board
GNDA: J6.2, J7.2, J8.2, J9.2, J10.2, J11.2, R15.2, R16.2, R17.2, R18.2, R19.2, R20.2; also elsewhere on the board
unnamed: C23.1, R15.1, U6.3 (+)
unnamed: C23.2, J6.1
unnamed: C24.1, R16.1, U6.5 (+)
unnamed: C24.2, J7.1
unnamed: C25.1, R17.1, U6.10 (+)
unnamed: C25.2, J8.1
unnamed: C26.1, R18.1, U6.12 (+)
unnamed: C26.2, J9.1
unnamed: C27.1, R19.1, U7.3 (+)
unnamed: C27.2, J10.1
unnamed: C28.1, R20.1, U7.5 (+)
unnamed: C28.2, J11.1

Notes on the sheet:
Front Left
Front Right
Rear Left
Rear Right
Center
Subwoofer

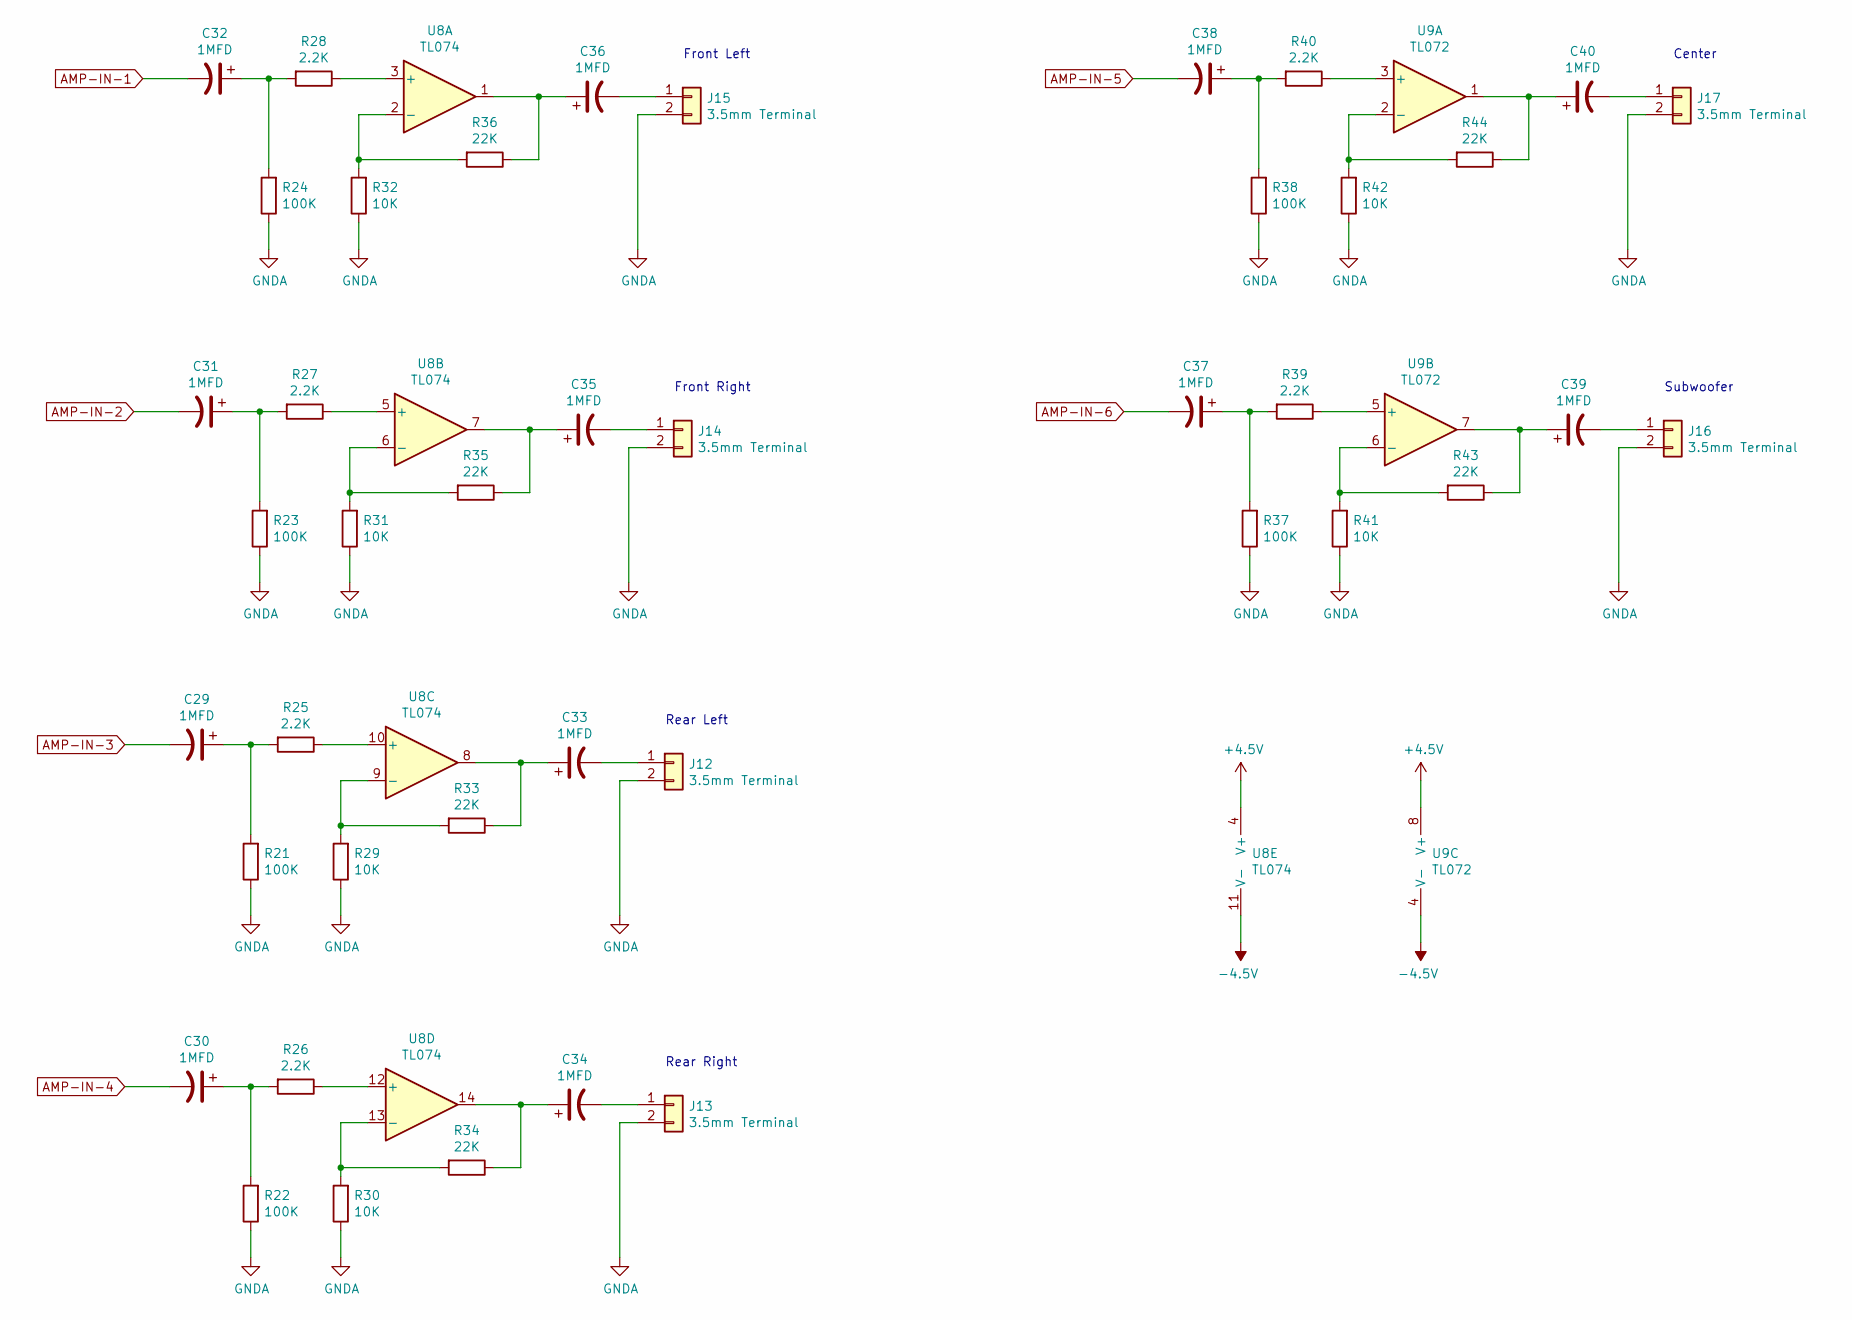
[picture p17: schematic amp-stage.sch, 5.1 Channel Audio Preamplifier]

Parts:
C29, C30, C31, C32, C33, C34, C35, C36, C37, C38, C39, C40: 1MFD; CP_Elec_4x5.3
J12, J13, J14, J15, J16, J17: 3.5mm Terminal; 3.50mm_PCB_Terminal
R21, R22, R23, R24, R37, R38: 100K; R_0805_2012Metric_Pad1.20x1.40mm_HandSolder
R25, R26, R27, R28, R39, R40: 2.2K; R_0805_2012Metric_Pad1.20x1.40mm_HandSolder
R29, R30, R31, R32, R41, R42: 10K; R_0805_2012Metric_Pad1.20x1.40mm_HandSolder
R33, R34, R35, R36, R43, R44: 22K; R_0805_2012Metric_Pad1.20x1.40mm_HandSolder
U8: TL074; SO-14_3.9x8.65mm_P1.27mm
U9: TL072; SO-8_3.9x4.9mm_P1.27mm

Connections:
+1V35: U8.4 (V+), U9.8 (V+); also elsewhere on the board
-5V: U8.11 (V-), U9.4 (V-); also elsewhere on the board
AMP-IN-1: C32.2; also elsewhere on the board
AMP-IN-2: C31.2; also elsewhere on the board
AMP-IN-3: C29.2; also elsewhere on the board
AMP-IN-4: C30.2; also elsewhere on the board
AMP-IN-5: C38.2; also elsewhere on the board
AMP-IN-6: C37.2; also elsewhere on the board
GNDA: J12.2, J13.2, J14.2, J15.2, J16.2, J17.2, R21.1, R22.1, R23.1, R24.1, R29.1, R30.1, R31.1, R32.1, R37.1, R38.1, R41.1, R42.1; also elsewhere on the board
unnamed: C29.1, R21.2, R25.2
unnamed: C30.1, R22.2, R26.2
unnamed: C31.1, R23.2, R27.2
unnamed: C32.1, R24.2, R28.2
unnamed: C33.1, R33.1, U8.8
unnamed: C33.2, J12.1
unnamed: C34.1, R34.1, U8.14
unnamed: C34.2, J13.1
unnamed: C35.1, R35.1, U8.7
unnamed: C35.2, J14.1
unnamed: C36.1, R36.1, U8.1
unnamed: C36.2, J15.1
unnamed: C37.1, R37.2, R39.2
unnamed: C38.1, R38.2, R40.2
unnamed: C39.1, R43.1, U9.7
unnamed: C39.2, J16.1
unnamed: C40.1, R44.1, U9.1
unnamed: C40.2, J17.1
unnamed: R25.1, U8.10 (+)
unnamed: R26.1, U8.12 (+)
unnamed: R27.1, U8.5 (+)
unnamed: R28.1, U8.3 (+)
unnamed: R29.2, R33.2, U8.9 (-)
unnamed: R30.2, R34.2, U8.13 (-)
unnamed: R31.2, R35.2, U8.6 (-)
unnamed: R32.2, R36.2, U8.2 (-)
unnamed: R39.1, U9.5 (+)
unnamed: R40.1, U9.3 (+)
unnamed: R41.2, R43.2, U9.6 (-)
unnamed: R42.2, R44.2, U9.2 (-)

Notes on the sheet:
Front Left
Front Right
Rear Left
Rear Right
Center
Subwoofer

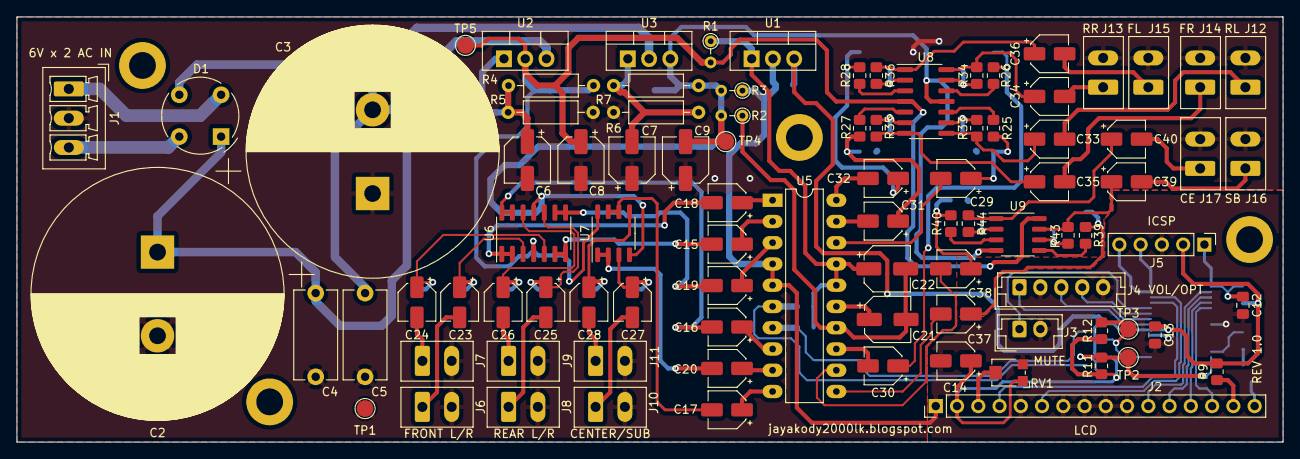
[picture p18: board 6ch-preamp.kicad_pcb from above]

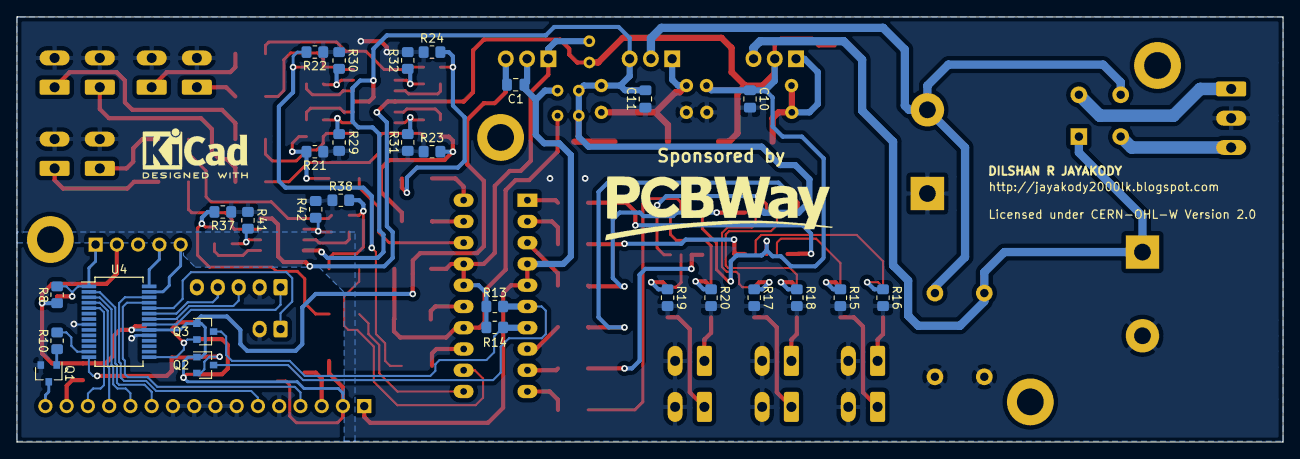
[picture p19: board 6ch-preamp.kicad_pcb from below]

Board: 2 copper layers, 151.3 x 50.8 mm, 124 parts (29 on the bottom side), 96 nets.

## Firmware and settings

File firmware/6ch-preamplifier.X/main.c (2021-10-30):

/*******************************************************************************
Copyright (c) 2021 Dilshan R Jayakody.

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
THE SOFTWARE IS PROVIDED "AS IS", WITHOUT WARRANTY OF ANY KIND, EXPRESS OR
IMPLIED, INCLUDING BUT NOT LIMITED TO THE WARRANTIES OF MERCHANTABILITY,
FITNESS FOR A PARTICULAR PURPOSE AND NONINFRINGEMENT. IN NO EVENT SHALL THE
AUTHORS OR COPYRIGHT HOLDERS BE LIABLE FOR ANY CLAIM, DAMAGES OR OTHER
LIABILITY, WHETHER IN AN ACTION OF CONTRACT, TORT OR OTHERWISE, ARISING FROM,
OUT OF OR IN CONNECTION WITH THE SOFTWARE OR THE USE OR OTHER DEALINGS IN THE
SOFTWARE.
*******************************************************************************/

#include <string.h>

#include "sysconfig.h"
#include "main.h"
#include "lcd.h"
#include "i2c.h"
#include "pt2258.h"
#include "util.h"

#define VOLUME_UPDATE_LEVEL 400

#define EEPROM_OFFSET_MODE      0x00
#define EEPROM_OFFSET_VOLUME    0x01
#define EEPROM_OFFSET_CHANNEL   0x02

__EEPROM_DATA(0xFF, 0x27, 0x00, 0x00, 0x00, 0x00, 0x00, 0x00);

void main(void) 
{
    uint16_t volumeIdleCounter;
    
    initSystem();
    i2cInit();
    __delay_ms(10);
    
    // Initialize LCD display.
    initLCD();
    clearLCD();
    
    // Turn on LCD back-light.
    PORTC = 0x04;
    
    // Allow time to initialize PT2258 with atleast 200ms delay.    
    printString("Initializing...", 15);    
    __delay_ms(500);
    
    // Insert mute symbols into LCD CGRAM.
    setGraphicRAM(LCD_CCHAR_SPEAKER, charSpeakerSymbol);
    setGraphicRAM(LCD_CCHAT_CROSS, charCrossSymbol);
    
    // Initialize PT2258 volume controller.    
    volControlInit();
    
    // Initialize global variables.    
    lastInputState = PORTB;
    sleepCounter = 0;
    updateMsg = 0x01;
    muteState = MUTE_OFF;
    volumeIdleCounter = 0;
    
    // Load EEPROM configuration and update global variables.
    masterVol = eeprom_read(EEPROM_OFFSET_VOLUME);
    if(masterVol > VOLUME_MAX_ATT)
    {
        // Invalid master attenuation level!
        masterVol = VOLUME_MAX_ATT;
    }
    
    channelMode = eeprom_read(EEPROM_OFFSET_MODE);
    if(!((channelMode == CHANNEL_MODE_CUSTOM) || (channelMode == CHANNEL_MODE_AUTO)))
    {
        // Invalid channel mode!
        channelMode = CHANNEL_MODE_CUSTOM;
    }
            
    // Restore master attenuation and channel attenuation levels.
    for(chCount = 0; chCount < MAX_CHANNEL_COUNT; chCount++)
    {
        // Load custom channel attenuation levels into RAM.
        chVol[chCount] = eeprom_read((EEPROM_OFFSET_CHANNEL + chCount));
        if(chVol[chCount] > VOLUME_MAX_ATT)
        {
            // Invalid channel attenuation level!
            chVol[chCount] = masterVol;
        }
        
        // Assign custom attenuation levels only if the mode is CUSTOM. 
        volSetChannelAtt(chCount, ((channelMode == CHANNEL_MODE_CUSTOM) ? chVol[chCount] : masterVol));
        __delay_ms(5);
    }
    
    // Activate audio outputs of the pre-amplifier.
    volSetMute(muteState);
    
    // Main service loop.
    while(1)
    {
        // Handle rotary encoder change events.
        if(((PORTB & 0x03) != 0x03) && (channelMode == CHANNEL_MODE_AUTO))
        {                        
            if(((PORTB & 0x01) == 0x00) && ((lastInputState & 0x01) == 0x01))
            {
                if(PORTB & 0x02)
                {
                    // Rotary encoder is changing on increment direction.
                    masterVol += ((masterVol >= VOLUME_MAX_ATT) ? 0 : 1);
                }
                else
                {
                    // Rotary encoder is changing on decrement direction.
                    masterVol -= ((masterVol == 0) ? 0 : 1);
                }
                
                // Request for LCD update.
                updateMsg = 0x01;
                sleepCounter = 0;
                volumeIdleCounter = VOLUME_UPDATE_LEVEL;
                volSetMasterAtt(masterVol);
            }
        }
        
        // Handle rotary switch press event (to access the system menu).
        if(((lastInputState & 0x04) == 0x00) && (PORTB & 0x04))
        {
            sleepCounter = 0;
            systemMenuHandler();
            updateMsg = 0x01;
        }
        
        // Handle mute button press event.
        if(((lastInputState & 0x08) == 0x00) && (PORTB & 0x08))
        {
            sleepCounter = 0;
            toggleMuteState();
            updateMsg = 0x01;            
        }
        
        // Handle LCD update due to master volume control changes.
        if(updateMsg & 0x01)
        {
            if(channelMode == CHANNEL_MODE_AUTO)
            {
                strncpy(lcdBuffer, "Att:   dB", 10);
                numToStrBuffer(&masterVol, lcdBuffer, 5);

                clearLCD();
                printString(lcdBuffer, 9);
            }
            else
            {
                clearLCD();
                printString("Custom Profile", 14);
            }
            
            updateMsg = 0;
            
            // Update mute symbol on LCD.
            displayMuteIcon();
        }
        
        // Detect idle state in volume control to update the EEPROM.
        if(volumeIdleCounter > 0)
        {
            volumeIdleCounter--;
            
            // Avoid multiple calls to update EEPROM (with volume).
            if(volumeIdleCounter == 2)
            {
                // Volume control is almost idle, lets write current volume level into EEPROM.
                eeprom_write(EEPROM_OFFSET_VOLUME, masterVol);
            }
        }
        
        // Check sleep counter status to enter LCD into sleep mode.
        if(sleepCounter >= SLEEP_COUNTER_LIMIT)
        {
            // Sleep timer exceed the idle limit.
            execIdleMode();
            
            lastInputState = PORTB;
            continue;
        }
                        
        lastInputState = PORTB;        
        __delay_ms(4);  
    }
    
    return;
}

void toggleMuteState()
{
    __delay_ms(150);
    
    muteState = (muteState == MUTE_ON) ? MUTE_OFF : MUTE_ON;
    volSetMute(muteState);    
}

void systemMenuHandler()
{
    uint8_t menuPos = 0, updateFlag = 1;
    uint8_t tempId;
    
    lastInputState = PORTB;
    
    while(1)
    {
        // Handle rotary encoder change events.
        if((PORTB & 0x03) != 0x03)
        {                        
            if(((PORTB & 0x01) == 0x00) && ((lastInputState & 0x01) == 0x01))
            {
                if(PORTB & 0x02)
                {
                    menuPos = ((menuPos == 7) ? 0 : (menuPos + 1));
                    if((channelMode == CHANNEL_MODE_AUTO) && (menuPos > 0) && (menuPos < 7))
                    {
                        // In AUTO mode user may not allow to change attenuation on each channel.
                        menuPos = 7;
                    }
                }
                else
                {
                    menuPos = ((menuPos == 0) ? 7 : (menuPos - 1));
                    if((channelMode == CHANNEL_MODE_AUTO) && (menuPos > 0) && (menuPos < 7))
                    {
                        // In AUTO mode user may not allow to change attenuation on each channel.
                        menuPos = 0;
                    }
                } 
                
                // Redraw menu item and value on LCD.
                sleepCounter = 0;
                updateFlag = 1;                
            }                        
        }
        
        // Handle mute button press event.
        if(((lastInputState & 0x08) == 0x00) && (PORTB & 0x08))
        {
            sleepCounter = 0;
            toggleMuteState();
            updateFlag = 1;
        }
        
        // Handle value change event.
        if(((lastInputState & 0x04) == 0x00) && (PORTB & 0x04))
        {
            // Clear pointer from menu item.
            setLocation(0, 1);
            sendChr(0x20);
            
            // Assign pointer to the menu value.
            setLocation(0, 2);
            sendChr(0x07E); 
            
            sleepCounter = 0;
            
            __delay_ms(50);
            
            // Display value edit option.
            if((menuPos > 0) && (menuPos < 7))
            {
                // Change channel attenuation value.
                tempId = menuPos - 1;
                changeChannelAttr(tempId, &(chVol[tempId]));
            }
            else if(menuPos == 0)
            {
                // Change channel mode.
                changeChannelMode(&channelMode);
            }
            else
            {
                // Exit from system menu.
                break;
            }
            
            // Clear pointer on value field.
            setLocation(0, 2);
            sendChr(0x020); 
            
            // Show selected menu item and value on exit.                        
            updateFlag = 1;
        }
        
        // Check for idle timer.
        if(sleepCounter >= SLEEP_COUNTER_LIMIT)
        {
            // Sleep timer exceed the idle limit.
            break;
        }
                        
        if(updateFlag)
        {
            clearLCD();
            strncpy(lcdBuffer, "  dB", 5);
            
            switch(menuPos)
            {
                case 0:
                    printString(" Channel Att", 12);
                    if(channelMode == CHANNEL_MODE_AUTO)
                    {
                        strncpy(lcdBuffer, "Automatic", 10);
                    }
                    else
                    {
                        strncpy(lcdBuffer, "Custom", 7);
                    }
                    break;
                case 1:
                    printString(" Front Left", 11);
                    numToStrBuffer(&(chVol[0]), lcdBuffer, 0);
                    break;
                case 2:
                    printString(" Front Right", 12);
                    numToStrBuffer(&(chVol[1]), lcdBuffer, 0);
                    break;    
                case 3:
                    printString(" Rear Left", 10);
                    numToStrBuffer(&(chVol[2]), lcdBuffer, 0);
                    break;
                case 4:
                    printString(" Rear Right", 11);
                    numToStrBuffer(&(chVol[3]), lcdBuffer, 0);
                    break;
                case 5:
                    printString(" Center", 7);
                    numToStrBuffer(&(chVol[4]), lcdBuffer, 0);
                    break;
                case 6:
                    printString(" Subwoofer", 10);
                    numToStrBuffer(&(chVol[5]), lcdBuffer, 0);
                    break;
                case 7:
                    printString(" Exit", 5);
                    break;
            }
            
            // Pointer is set to menu item (root menu).
            setLocation(0, 1);
            sendChr(0x07E);
            
            // Show attenuation level / menu parameter of the selected channel (except EXIT menu item).
            if(menuPos != 7)
            {
                setLocation(1, 2);
                printString(lcdBuffer, 11); 
            }
            
            // Update mute symbol on LCD.
            displayMuteIcon();
                                   
            updateFlag = 0;
        }
                
        lastInputState = PORTB;        
        __delay_ms(5);
    }
}

void changeChannelMode(uint8_t *value)
{
    uint8_t updateFlag = 1, tmpPos;
    
    lastInputState = PORTB;
    
    while(1)
    {
        // Handle rotary encoder change events.
        if((PORTB & 0x03) != 0x03)
        {
            if(((PORTB & 0x01) == 0x00) && ((lastInputState & 0x01) == 0x01))
            {                
                // Toggle mode between AUTO and MANUAL (in both directions).
                if((*value) == CHANNEL_MODE_AUTO)
                {
                    (*value) = CHANNEL_MODE_CUSTOM;
                    
                    // Load custom attenuation configuration into each channel.
                    for(tmpPos = 0; tmpPos < MAX_CHANNEL_COUNT; tmpPos++)
                    {
                        volSetChannelAtt(tmpPos, chVol[tmpPos]);
                        __delay_ms(5);
                    }
                }
                else
                {
                    (*value) = CHANNEL_MODE_AUTO;
                    
                    // Set attenuation of all 6 channels to one level.
                    volSetMasterAtt(masterVol);
                }
                                
                sleepCounter = 0;
                updateFlag = 1;
            }
        }
        
        // Refresh value on LCD based on update flag.
        if(updateFlag)
        {
            if((*value) == CHANNEL_MODE_AUTO)
            {
                strncpy(lcdBuffer, "Automatic", 10);
            }
            else
            {
                strncpy(lcdBuffer, "Custom   ", 10);
            }
            
            setLocation(1, 2);
            printString(lcdBuffer, 10);
            
            // Update mute symbol on LCD.
            displayMuteIcon();
            
            updateFlag = 0;
        }
        
        // Check for exit event.
        if(((lastInputState & 0x04) == 0x00) && (PORTB & 0x04))
        {
            // Save selected mode into EEPROM.
            sleepCounter = 0;
            eeprom_write(EEPROM_OFFSET_MODE, (*value));
            break;
        }
        
        // Check for idle timer.
        if(sleepCounter >= SLEEP_COUNTER_LIMIT)
        {
            // Sleep timer exceed the idle limit.
            break;
        }
        
        // Handle mute button press event.
        if(((lastInputState & 0x08) == 0x00) && (PORTB & 0x08))
        {
            sleepCounter = 0;
            toggleMuteState();
            updateFlag = 1;
        }
                
        lastInputState = PORTB;        
        __delay_ms(5);
    }
}

void changeChannelAttr(uint8_t channel, uint8_t *value)
{      
    uint8_t updateFlag = 1;
    
    lastInputState = PORTB;  
    
    while(1)
    {
        // Handle rotary encoder change events.
        if((PORTB & 0x03) != 0x03)
        {                        
            if(((PORTB & 0x01) == 0x00) && ((lastInputState & 0x01) == 0x01))
            {
                if(PORTB & 0x02)
                {
                    (*value) += (((*value) >= VOLUME_MAX_ATT) ? 0 : 1);
                }
                else
                {
                    (*value) -= (((*value) == 0) ? 0 : 1);
                }
                
                updateFlag = 1;
            }
            
            sleepCounter = 0;
        }
                
        // Refresh value on LCD based on update flag.
        if(updateFlag)
        {
            setLocation(1, 2);
            strncpy(lcdBuffer, "  dB", 5);
            
            numToStrBuffer(value, lcdBuffer, 0);
            printString(lcdBuffer, 4); 
            
            // Update mute symbol on LCD.
            displayMuteIcon();
            
            volSetChannelAtt(channel, (*value));            
            updateFlag = 0;
        }
        
        // Check for exit event.
        if(((lastInputState & 0x04) == 0x00) && (PORTB & 0x04))
        {
            // Save current channel value into EEPROM.
            sleepCounter = 0;
            eeprom_write((EEPROM_OFFSET_CHANNEL + channel), (*value));            
            break;
        }
        
        // Handle mute button press event.
        if(((lastInputState & 0x08) == 0x00) && (PORTB & 0x08))
        {
            sleepCounter = 0;
            toggleMuteState();
            updateFlag = 1;
        }
        
        // Check for idle timer.
        if(sleepCounter >= SLEEP_COUNTER_LIMIT)
        {
            // Sleep timer exceed the idle limit.
            break;
        }
        
        lastInputState = PORTB;        
        __delay_ms(5);
    }
}

void displayMuteIcon()
{
    // Update mute symbol at lower right corner of the LCD.
    setLocation(14, 2);

    if(muteState == MUTE_ON)
    {
        // Audio output is mute.
        sendChr(LCD_CCHAR_SPEAKER);
        sendChr(LCD_CCHAT_CROSS);
    }
    else
    {
        // Audio output is online.
        sendChr(0x20);
        sendChr(0x20);
    }
}

void execIdleMode()
{
    // Turn off LCD back-light.
    PORTC &= 0xFB;
    lastInputState = PORTB; 
    
    // Stop sleep timer.
    PIE1 &= 0xFE;
    
    while(1)
    {
        if((lastInputState & 0x0F) != (PORTB & 0x0F))
        {
            // User action detected and break the idle state.
            sleepCounter = 0;
            
            // Restart sleep timer.
            TMR1H = 11;
            TMR1L = 220;
    
            PIR1 = 0x00;
            PIE1 = 0x01;
            
            break;
        }
        
        lastInputState = PORTB;        
        __delay_ms(5);
    }
    
    // Turn on LCD back-light.
    PORTC |= 0x04;
}

void __interrupt() isrMain(void)
{
    if(PIR1 & 0x01)
    {
        if(sleepCounter <= SLEEP_COUNTER_LIMIT)
        {
            sleepCounter++;
        }
        
        // Restart TIMER1 with 500ms interval.
        TMR1H = 11;
        TMR1L = 220;
    
        PIR1 = 0x00;
        PIE1 = 0x01;               
    }
}

void initSystem()
{    
    // Enable internal pull-ups on PORTB.
    OPTION_REG = 0x7F;
    
    // RA0...RA3 : [OUT] 1602 (HD44780) LCD - DATA4..DATA7
    PORTA = 0x00;
    TRISA = 0x00;
        
    // RB0 : [IN] Rotary encoder input 1.
    // RB1 : [IN] Rotary encoder input 2.
    // RB2 : [IN] Rotary encoder push switch input.
    // RB3 : [IN] Mute button input.
    // RB4 : [OUT] 1602 (HD44780) LCD - RS [4]
    // RB5 : [OUT] 1602 (HD44780) LCD - En [6]
    PORTB = 0x00;
    TRISB = 0x0F;
    WPUB = 0x0F;
    
    // RC2 : [OUT] LCD back-light control.
    // RC3 : [IN] I2C[SCL] - PT2258 SCL
    // RC4 : [IN] I2C[SDA] - PT2258 SDA
    PORTC = 0x00;
    TRISC = 0x18;
        
    // Disable unused peripherals such as ADC, comparator, ECCP, etc.
    ADCON0 = 0x00;
    ADCON1 = 0x00;
    ANSEL = 0x00;  
    ANSELH = 0x00;
    
    CM1CON0 = 0x00;
    CM2CON0 = 0x00;
    
    CCP1CON = 0x00;

    // Reset SSP control register to known state (for I2C).
    SSPCON = 0x00;
    
    // Initialize TIMER1 with 500ms interval as sleep counter.
    T1CON = 0x3D;
    TMR1H = 11;
    TMR1L = 220;
    
    // Enable interrupts from TIMER1.
    PIR1 = 0x00;
    PIE1 = 0x01;
    INTCON = 0xC0;
}

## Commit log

2021-10-26 Add initial version of KiCAD design files and heatsink design.
    [6ch-preamp.kicad_pcb, 6ch-preamp.sch, amp-stage.sch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]
2021-10-26 Update KiCAD design files with GitHub repository link.
    [6ch-preamp.kicad_pcb, 6ch-preamp.sch, amp-stage.sch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]
2021-11-01 Add initial version of wiring diagram project.
    [6ch-wire-diagram.sch, audioin.sch]

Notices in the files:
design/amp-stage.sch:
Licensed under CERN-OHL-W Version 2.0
